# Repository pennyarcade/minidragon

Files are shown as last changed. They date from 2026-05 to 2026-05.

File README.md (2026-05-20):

# MiniDragon

Schematics, hardware simulator and software files for the MiniDragon CPU. This is a from-scratch CPU that I designed and am implementing using transistors, capacitors, resistors and diodes. The goal is to make an 8-bit CPU that could be used for general-purpose computing. There are a lot of toy instruction sets floating around on the web. I chose instead to design my own, loosely based off of the PDP and 6502. It is a single accumulator design with a pair of 16-bit stack pointers and a pair of temporary 8-bit registers. Instructions are 8 bits, operands are 8 bits from memory, temporary registers or immediate, and running software can access all 16 bits of memory available to the CPU. Eventually, I want the assembled CPU along with some external RAM, ROM and a serial interface chip to be self-hosting. So, I hope to eventually have a built-in assembler or BASIC interpreter in the ROM.

## Layout

The layout is separated into logical components:

 * Microcode counter. This keeps track of what microcode in the current instruction we are operating on.
 * Instruction decoder logic. This consists of an instruction register and a series of ROM boards made out of jumpers. This uses the microcode counter as well as its own internal combinatorial logic to select one instruction and output control signals to the rest of the CPU.
 * Registers. These exist on various busses, and their input/output is controlled by the instruction decoder logic's control signals.
 * Constant circuits. These can output either a zero or an immediate value sign extended from the current instruction register. Their operation is controlled by the instruction decoder's control signals.
 * ALU. This is built out of a series of smaller components on its own internal bus. Selection of which operation as well as which input is controlled via the instruction decoder logic's control signals.
 * Flags handling. This consists of a few registers to hold flags generated by the ALU and put them on the data bus when appropriate. This is controlled via the control signal lines much like the rest of the non-instruction decoder components.
 * Memory interface. This provides the glue so that the CPU can be seen as having a set of address and data lines as well as an output enable and write enable line, much like a traditional non-SOC CPU.

### Internal Busses

 * 16-bit data bus. Most registers can only read from or write to the lower 8 bits of this bus, but some can also output their value to the upper 8 bits. Various 16-bit registers are able to read the entire 16-bit bus, and this is how the upper bits of the instruction pointer and stack pointers can be read. The lower 8 bits of this will feed the external data IO lines.
 * 16-bit address bus. This feeds the external address requests by the CPU and is driven by both the instruction pointer and stack pointers.
 * 16-bit ALU source bus. This allows the ALU A source to be controlled, so that various 16-bit registers we want to add/subtract from don't need to be placed in a temporary location.

### Registers

 * 16-bit instruction pointer register (IP), holding the address of the current instruction in memory. Its value can be placed on the address bus or ALU input bus and it can read from the data bus. Software can jump relative to the current instruction, as well as pushing the current IP to the stack (controlled by the PC combined register), pop the IP from the stack or jump to an immediate 16 bit address.
 * 8-bit instruction register (IR), holding the current instruction that was fetched from memory. It is write-only and feeds microcode decoding logic, but can read from the data bus. Software cannot directly set this, but memory is modifiable so self-modifying code is possible.
 * 8-bit accumulator register (A), holding the current accumulated result. It can read from and write to the data bus, and it can output to the ALU input bus. Many instructions available to software can directly manipulate this register. Its value can be moved to and from the P and C registers as well as added to the combined PC register, allowing it to be used for indirect memory address modes as well.
 * 8-bit ALU temporary register (B), holding a temporary value from the bus. It can read from and write to the data bus. Its output is also hardcoded to the second input of the ALU. Software has no capability to modify this register and it is used by various microcodes to accomplish virtually all CPU operations. When the ALU is operating on a 16-bit number, the B register will be sign-extended to 16 bits.
 * 8-bit memory page register (P) and 8-bit memory cell register (C), together holding a 16-bit address. The P and C registers can individually read from the data bus, and the combined PC value can be output to the address bus or the ALU input bus. Software can write to the P and C registers from the A register and can use the combined PC register contents to load from and store to memory. Some ALU operations allow the memory address pointed at by the PC register to be used as an operand for ALU operations against the accumulator (A). The current value of the instruction pointer (IP) can be pushed to or popped from memory referred to by this register. The current value of the shadow PC combined register can also be pushed to or popped from memory referred to by this register.
 * 8-bit shadow page register (SP) and 8-bit shadow cell register (SC), together holding a 16-bit address referred to as SPC. This is not directly addressable, but its current value can be pushed to or popped from the location pointed at by the PC register, and a SWAP instruction allows software to swap the PC and SPC registers.
 * 8-bit CPU data register (D), holding temporary values when the CPU is pushing or popping a 16-bit value off of the stack (PC). We could use the A register for this, but I wanted to make sure that the accumulator was not clobbered when performing stack operations. This is not user readable or writeable.
 * 8-bit temporary registers (U and V), available to the programmer for various operations. These can be moved to from A, swapped to from A or each other, loaded from and stored to memory, and can be used as operands for ALU operations against the accumulator (A).
 * 3-bit flags register, containing a carry flag (CF), a zero flag (ZF) and a shadow PC flag (PC). Software cannot directly set or clear the carry or zero flags, but both carry and zero flags are set appropriately when carrying out any ALU-based operation which sources from and stores to the A register. It is not directly readable by software but there exist skip instructions that allow software to conditionally execute a particular instruction if either CF or ZF is set or cleared. Additionally, several ALU operations allow using the carry flag as an input to chain operations together for 16 and 32 bit arithmetic. The PC flag is toggleable using a special SWAP instruction.

### Instructions

 * JRI - Jump relative to immediate sign-extended + 1. Assembler also supports labels. Can jump 32 forward or backward relative to next instruction. Specifically designed such that "JRI 0" jumps to the next instruction and is encoded as all zeros.
 * LOADI - Load immediate stored in next memory cell to A. Can load any 8-bit value. Skips over that value after executing since it is not a valid instruction.
 * ADDI - Add immediate sign-extended to A, no carry. Can add values between -32 and 31. Affects ZF and CF.
 * INV - Bitwise invert A. Affects ZF and CF.
 * SHL - Shift A left by 1, setting the bottom bit to 0, set carry to top bit shifted out. Affects ZF and CF.
 * SHR - Shift A right by 1, setting the top bit to 0, set carry to bottom bit shifted out. Affects ZF and CF.
 * RCL - Shift A left by 1, setting bottom bit to the carry flag, set carry to top bit shifted out. Affects ZF and CF.
 * RCR - Shift A right by 1, setting top bit to the carry flag, set carry to bottom bit shifted out. Affects ZF and CF.
 * ROL - Shift A left by 1, setting the bottom bit to the shifted out top bit, set carry to top bit shifted out. Affects ZF and CF.
 * ROR - Shift A right by 1, setting the top bit to the shifted our bottom bit, set carry to bottom bit shifted out. Affects ZF and CF.
 * ADD - Add contents of memory location PC to A register. Affects ZF and CF.
 * ADC - Add contents of memory location PC to A register, with carry in from flags. Affects ZF and CF.
 * AND - And contents of memory location PC against A register. Affects ZF and CF.
 * OR - Or contents of memory location PC against A register. Affects ZF and CF.
 * XOR - XOR contents of memory location PC against A register. Affects ZF and CF.
 * ADDU - Add contents of U to A register. Affects ZF and CF.
 * ADCU - Add contents of U to A register, with carry in from flags. Affects ZF and CF.
 * ANDU - And contents of U against A register. Affects ZF and CF.
 * ORU - Or contents of U against A register. Affects ZF and CF.
 * XORU - XOR contents of U against A register. Affects ZF and CF.
 * ADDV - Add contents of V to A register. Affects ZF and CF.
 * ADCV - Add contents of V to A register, with carry in from flags. Affects ZF and CF.
 * ANDV - And contents of V against A register. Affects ZF and CF.
 * ORV - Or contents of V against A register. Affects ZF and CF.
 * XORV - XOR contents of V against A register. Affects ZF and CF.
 * ADDPCI - Add immediate to PC. Can add any value between 1 and 32 inclusive. Since we only have the capability of sign-extending the bottom 4 or 6 bits of an instruction to use as an immediate, this intentionally chooses an instruction prefix which sets the 6th bit to 0, in order to simplify decoding logic as well as keep the immediate register simple. This is why there is a separate ADDPCI and SUBPCI instruction.
 * SUBPCI - Subtract immediate from PC. Can subtract any value between 1 and 32 inclusive. Much like ADDPCI, this uses a clever trick where the 6th bit in the instruction prefix is set to 1, in order to correctly sign-extend the immediate.
 * ADDPC - Add A register sign-extended from 8 to 16 bits to the PC register.
 * ATOP - Load contents of A register to P.
 * ATOC - Load contents of A register to C.
 * PTOA - Load contents of P register to A.
 * CTOA - Load contents of C register to A.
 * ATOU - Load contents of A register to U.
 * ATOV - Load contents of A register to V.
 * UTOA - Load contents of U register to A.
 * VTOA - Load contents of V register to A.
 * LOADA - Load contents of memory location pointed at by PC to A register.
 * STOREA - Store contents of A register to memory location pointed at by PC.
 * LOADU - Load contents of memory location pointed at by PC to U register.
 * STOREU - Store contents of U register to memory location pointed at by PC.
 * LOADV - Load contents of memory location pointed at by PC to V register.
 * STOREV - Store contents of V register to memory location pointed at by PC.
 * SKIPIF - Skip next instruction if carry/zero flag set/cleared. To save on decoding logic, the lower 3 bits of the SKIPIF instruction feed combinatorial logic in the flags register. This leaves us with four undefined instructions which would, if executed, choose to operate on either both or neither of the carry and zero flag simultaneously.
 * LNGJUMP - Jumps to address stored in memory location IP + 1 and IP + 2, stored in big-endian.  Skips over the two values after executing since they are not valid instructions.
 * SWAPAU - Swap contents of A and U registers.
 * SWAPAV - Swap contents of A and V registers.
 * SWAPUV - Swap contents of U and V registers.
 * SWAPPC - Swap PC and SPC registers, making the current PC into the shadow PC and vice versa.
 * PUSHIP - Subtracts two from PC, stores IP + immediate into location PC and PC + 1 big endian. Immediate can be a positive integer between 0 and 7 inclusive and is often non-zero in order to store the correct return address of a subroutine call.
 * POPIP - Jumps to data stored in memory location PC and PC + 1 big endian, adds 2 to PC.
 * PUSHSPC - Subtracts two from PC, stores SPC into location PC and PC + 1 big endian.
 * POPSPC - Loads SPC with value stored in memory location PC and PC + 1 big endian, adds 2 to PC.

### Assembler-Provided Macros

For convenience of programming without too much hassle, several assembler macros which are encoded to a series of the above instructions are available:

 * NOP - Perform no operation. Implemented as "JRI 0", which as noted above is encoded as a null byte.
 * HALT - Jump to self, loop forever. Implemented as "JRI -1".
 * ZERO - Zero the contents of A. Implemented as "LOADI 0".
 * SETPC - Set immediate value to PC register, clobbering A register. Sets PC to full 16-bit value. Implemented as a pair of "LOADI" instructions followed by the appropriate "ATOP" and "ATOC". Takes an optional second parameter which is applied as an integer offset to the 16-bit value.
 * INCPC - Add 1 to PC. Implemented as "ADDPCI 1".
 * DECPC - Subtract 1 from PC. Implemented as "SUBPCI 1".
 * STOREI - Stores immediate value to memory pointed at by PC register, clobbering A register. Stores full 8-bit value to memory. Implemented as a "LOADI" followed by a "STOREA".
 * NEG - Twos compliment negate A register. Implemented as an "INV" followed by an "ADDI 1".
 * INC - Increment A register. Implemented as an "ADDI 1".
 * DEC - Decrement A register. Implemented as an "ADDI -1".
 * RET - Return from subroutine (identical to POPIP).
 * JRIZ - Jump relative if zero flag set. Implemented using "SKIPIF" and "JRI".
 * JRINZ - Jump relative if zero flag not set. Implemented using "SKIPIF" and "JRI".
 * JRIC - Jump relative if carry flag set. Implemented using "SKIPIF" and "JRI".
 * JRINC - Jump relative if carry flag not set. Implemented using "SKIPIF" and "JRI".
 * LNGJUMPZ - Jump to address if zero flag set. Implemented using "SKIPIF", "JRI" and "LNGJUMP".
 * LNGJUMPNZ - Jump to address if zero flag not set. Implemented using "SKIPIF", "JRI" and "LNGJUMP".
 * LNGJUMPC - Jump to address if carry flag set. Implemented using "SKIPIF", "JRI" and "LNGJUMP".
 * LNGJUMPNC - Jump to address if carry flag not set. Implemented using "SKIPIF", "JRI" and "LNGJUMP".
 * CALL - Subtracts two from PC, stores the next instruction after this instruction to PC, then jumps to the immediate address. Return from this using “RET”. Implemented using a "PUSHIP" and a "LNGJUMP".
 * CALLRI - Subtracts two from PC, stores the next instruction after this instruction to PC, then jumps to the relative offset from the next instruction. Return from this using “RET”. Implemented using a "PUSHIP" and a "JRI" instruction, meaning it is only useful for subroutines located close in memory. However, it can save several bytes.
 * PUSH x - Subtracts operand size from PC, stores the value of A/U/V/IP/SPC into the memory location PC. This is simply a virtual instruction that maps to "STOREA", "STOREU", "STOREV", "PUSHIP" or "PUSHSPC", so that the correct instruction doesn't have to be remembered.
 * PUSHI - Subtracts 1 from PC, stores immediate to memory location PC, clobbering A register. Implmented as a "DECPC" followed by a "STOREI" macro.
 * PUSHADDR - Subtracts 1 from PC, stores low byte of 16-bit immediate value to memory location PC, clobbering A register. Then subtracts 1 again from the PC, stores the high byte of 16-bit immediate value to memory location PC, clobbering the A register again. Implemented as a pair of "DECPC" and "STOREI" macros. Takes an optional second parameter which is applied as an integer offset to the 16-bit value.
 * POP x - Loads the value of memory location PC into A/U/V/IP/SPC, adds operand size to PC. Works identically to "PUSH x" as a virtual instruction alias to several concrete instructions.
 * LOAD x - Loads the value pointed at in memory by PC to A/U/V. Alias for the various concrete load instructions, similar to "PUSH x" and "POP x".
 * STORE x - Stores the value in A/U/V into the memory location pointed at by PC. Alias for the various concrete store instructions, similar to "PUSH x" and "POP x".
 * SWAP x, y - Swaps the contents of a pair of registers. Valid pairs are either from A/U/V or PC/SPC. Alias for the various concrete swap instructions, similar to "PUSH x", "POP x", "LOAD x" and "STORE x".
 * MOV x, y - Moves the contents of the x register into the y register. Any register A/U/V/P/C can be moved to or from as long as one of the operands is the A register. Alias for the various concrete load instructions, similar to "SWAP x, y".

### Opcode Layout

The 8-bit space for a single opcode is split up in order to make it possible to decode instructions using the least amount of logic. There are some holes where future instructions might be added. For now, undefined instructions will produce undefined behavior in the CPU. As currently implemented, the control logic will output all 1's for all control signals of undefined or un-mapped instructions. For this layout, the following conventions are used:

 * Register name - Register names listed directly refer to the value of that register. So, `A + 1` would refer to an operation that takes the value of A and adds 1.
 * `>` - Right carat, implies that the result of the operation on the left is stored to register/location on the right.
 * `[` and `]` - Dereference. This implies that the value of what is inside the `[]` is an address where we will store. So `1 > [PC]` implies that the value of "1" would be stored to the 8-bit memory location referenced by the PC combined register.
 * `{` and `}` - Register operand from the opcode itself. Currently, register operands are defined as follows:
   * `00` - Undefined, no register mapping.
   * `01` - U register.
   * `10` - V register.
   * `11` - SRAM pointed at by PC register.

<pre>
opcpde            description                         implementation                 mnemonic        alias
----------------------------------------------------------------------------------------------------------

<b>y y y y y y y y   immediate op</b>
0 0 x x x x x x   jump to immediate offset            IP + imm + 1 > IP              JRI x
0 1 x x x x x x   add immediate to A                  A + imm -> A                   ADDI x

<b>1 0 0 y y y y y   stack immediate op</b> †1
1 0 0 0 0 x x x   push IP + immediate                 PC - 2 > PC, IP + imm > [PC]   PUSHIP x        PUSH IP + x

<b>1 0 0 s s y y y   arithmetic op with operand</b> †2
1 0 0 s s 0 0 0
1 0 0 s s 0 0 1   add from [PC]/U/V                   A + {ss} > A                   ADD/ADDU/ADDV
1 0 0 s s 0 1 0   add with carry from [PC]/U/V        A + {ss} + CF > A              ADC/ADCU/ADCV
1 0 0 s s 0 1 1   and from [PC]/U/V                   A & {ss} > A                   AND/ANDU/ANDV
1 0 0 s s 1 0 0   or from [PC]/U/V                    A | {ss} > A                   OR/ORU/ORV
1 0 0 s s 1 0 1   xor from [PC]/U/V                   A ^ {ss} > A                   XOR/XORU/XORV
1 0 0 s s 1 1 0   <i>see tables below</i>
1 0 0 s s 1 1 1   <i>see tables below</i>

<b>1 0 0 s s y y y   arithmetic op against U</b>
1 0 0 0 1 0 0 0
1 0 0 0 1 0 0 1   <i>add from U</i>
1 0 0 0 1 0 1 0   <i>add with carry from U</i>
1 0 0 0 1 0 1 1   <i>and from U</i>
1 0 0 0 1 1 0 0   <i>or from U</i>
1 0 0 0 1 1 0 1   <i>xor from U</i>
1 0 0 0 1 1 1 0   rotate left A                       A << 1 + ((A >> 7) & 0x01) > A ROL
1 0 0 0 1 1 1 1   rotate right A                      A >> 1 + ((A << 7) & 0x80) > A ROR

<b>1 0 0 s s y y y   arithmetic op against V</b>
1 0 0 1 0 0 0 0
1 0 0 1 0 0 0 1   <i>add from V</i>
1 0 0 1 0 0 1 0   <i>add with carry from V</i>
1 0 0 1 0 0 1 1   <i>and from V</i>
1 0 0 1 0 1 0 0   <i>or from V</i>
1 0 0 1 0 1 0 1   <i>xor from V</i>
1 0 0 1 0 1 1 0   rotate left with carry A            A << 1 + CF > A                RCL
1 0 0 1 0 1 1 1   rotate right with carry A           A >> 1 + (CF << 7) > A         RCR

<b>1 0 0 s s y y y   arithmetic op against [PC]</b>
1 0 0 1 1 0 0 0
1 0 0 1 1 0 0 1   <i>add from [PC]</i>
1 0 0 1 1 0 1 0   <i>add with carry from [PC]</i>
1 0 0 1 1 0 1 1   <i>and from [PC]</i>
1 0 0 1 1 1 0 0   <i>or from [PC]</i>
1 0 0 1 1 1 0 1   <i>xor from [PC]</i>
1 0 0 1 1 1 1 0   shift left A                        A << 1 > A                     SHL
1 0 0 1 1 1 1 1   shift right A                       A >> 1 > A                     SHR

<b>1 0 1 y y y y y   pc subtract op</b> †3
1 0 1 x x x x x   Subtract immediate from PC          PC - imm - 1 > PC              SUBPCI x

<b>1 1 0 y y y y y   pc add op</b> †4
1 1 0 x x x x x   Add immediate to PC                 PC + imm + 1 > PC              ADDPCI x

<b>1 1 1 0 0 y y y   register op</b>
1 1 1 0 0 0 0 0   load from address P + C to U        [P | C] > U                    LOADU           LOAD U
1 1 1 0 0 0 0 1   store to address P + C from U       U > [P | C]                    STOREU          STORE U
1 1 1 0 0 0 1 0   load from address P + C to V        [P | C] > V                    LOADV           LOAD V
1 1 1 0 0 0 1 1   store to address P + C from V       V > [P | C]                    STOREV          STORE V
1 1 1 0 0 1 0 0   swap A and U                        A > U, U > A                   SWAPAU          SWAP A, U/SWAP U, A
1 1 1 0 0 1 0 1   swap A and V                        A > V, V > A                   SWAPAV          SWAP A, V/SWAP V, A
1 1 1 0 0 1 1 0   swap U and V                        U > V, V > U                   SWAPUV          SWAP U, V/SWAP V, U
1 1 1 0 0 1 1 1   swap PC and SPC                     PC > SPC, SPC > PC             SWAPPC          SWAP PC, SPC/SWAP SPC, PC

<b>1 1 1 0 1 y y y   memory op</b>
1 1 1 0 1 0 0 0   load page register from A           A > P                          ATOP            MOV A, P
1 1 1 0 1 0 0 1   load cell register from A           A > C                          ATOC            MOV A, C
1 1 1 0 1 0 1 0   store page register to A            P > A                          PTOA            MOV P, A
1 1 1 0 1 0 1 1   store cell register to A            C > A                          CTOA            MOV C, A
1 1 1 0 1 1 0 0   load U register from A              A > U                          ATOU            MOV A, U
1 1 1 0 1 1 0 1   load V register from A              A > V                          ATOV            MOV A, V
1 1 1 0 1 1 1 0   store U register to A               U > A                          UTOA            MOV U, A
1 1 1 0 1 1 1 1   store V register to A               V > A                          VTOA            MOV V, A

<b>1 1 1 1 0 y y y   status op</b> †5
1 1 1 1 0 0 0 0   invert A                            ~A > A                         INV
1 1 1 1 0 0 0 1
1 1 1 1 0 0 1 0   skip next instruction if CF         IP + 1 + CF > IP               SKIPIF CF
1 1 1 1 0 0 1 1   skip next instruction if !CF        IP + 1 + !CF > IP              SKIPIF !CF
1 1 1 1 0 1 0 0   skip next instruction if ZF         IP + 1 + ZF > IP               SKIPIF ZF
1 1 1 1 0 1 0 1   skip next instruction if !ZF        IP + 1 + !ZF > IP              SKIPIF !ZF
1 1 1 1 0 1 1 0   invert A                            ~A > A                         INV
1 1 1 1 0 1 1 1

<b>1 1 1 1 1 y y y   stack op</b>
1 1 1 1 1 0 0 0   jump to immediate                   [IP + 1] > IP                  LNGJUMP x
1 1 1 1 1 0 0 1   load immediate                      [IP + 1] -> A                  LOADI x
1 1 1 1 1 0 1 0   add to PC                           PC + A > PC                    ADDPC
1 1 1 1 1 0 1 1   pop IP                              [PC] > IP, PC + 2 > PC         POPIP           POP IP
1 1 1 1 1 1 0 0   push SPC                            PC - 2 > PC, SPC > [PC]        PUSHSPC         PUSH SPC
1 1 1 1 1 1 0 1   pop SPC                             [PC] > SPC, PC + 2 > PC        POPSPC          POP SPC
1 1 1 1 1 1 1 0   load from address P + C             [P | C] > A                    LOADA           LOAD A
1 1 1 1 1 1 1 1   store to address P + C              A > [P | C]                    STOREA          STORE A
</pre>

 * †1 This instruction occupies the same space as the ALU operations. This is why register operand {00} is undefined. The instruction decoder will not select the ALU operation decoder board when "PUSHIP" is detected.
 * †2 This might be slightly misleading, given that the register operand {00} is not only undefined but also not mapped to ALU operations. See †1 for details.
 * †3 Due to only being able to sign-extend the lower 4 or 6 bits of an instruction, this cleverly puts itself into an instuction slot where the 6th bit is 1.
 * †4 Due to only being able to sign-extend the lower 4 or 6 bits of an instruction, this cleverly puts itself into an instuction slot where the 6th bit is 0.
 * †5 I've shoved some arithmetic instructions that do not use a "B" operand here. We decode them versus a SKIPIF by doing an XOR/EQUALITY on the 2nd and 3rd bit, making them map to two places in the ISA. When in SKIPIF mode, we use the lower 3 bits as selector signals for combinatorial logic. The lowest bit is used as an "invert selected flags signal" bit, and the next two bits are used as "CF select" and "ZF select". This is why we can map unrelated instructions to when the last two bits are 00 or 11, since those would map to "neither CF or ZF" and "both CF and ZF" respectively.

## Design Concessions

As was the case with many 8-bit CPUs in the last century, this CPU does not have included memory, either volatile or non-volatile. It instead will assume an external chip or set of chips present on its external address and data bus. These chips, in the interest of practicality, will be standard TTL DIP package chips providing 32KB of SRAM, 30KB of ROM and 2KB of IO address space in which I am currently planning to place an 8-bit serial chip to talk to a VT-100 terminal. Other plans include an RTCRAM chip for settings and clock support, a GPIO chip, and room for additional expansion chips.

Due to the sheer number of parts involved in making a register as well as the control logic needed in order to select registers for ALU operations, there are only two scratch registers. Most intermediate values must therefore be stored on the stack. Various core library operations were sped up significantly when adding the U and V registers as slower stack manipulation operations could be dropped. Additional speedups as well as easier implementation of core functionality could be realized by adding additional scratch registers. However, this would increase the complexity of the instruction decoding logic and require a necessary juggling of instructions in the above table.

Similarly, due to the complexity of such a circuit, no number comparison instructions are present. Instead, comparison functions are implemented in the stdlib by bitwise comparing two numbers from top to bottom bit. This makes a lot of functions such as integer conversion and division functions much slower than they need to be. Due to this, I'm considering possibly adding a compare function to the ALU and placing it in place of the INV instruction. INV would move to the unused opcode in the status op block, at which case I would have room to implement a hardware NEG. I've experimented with this on a separate branch and the gains are significant. Alternatively, its possible to design an external math coprocessor. This is similar to contemporary CPUs with a floating point or math coprocessor so would not be out of the question. If this happens, the standard library should be updated to call the coprocessor instead of perofrming comparisons, multiplication and division on-CPU.

Because of the complexity of designing such a system from scratch, there are a lot of inefficiencies in how the various circuits are assembled. In many cases, buffers are not actually necessary and add to propagation delay. In order to make the project manageable by a single creature, I've decided to sacrifice any sort of speed for modularity. This will result in a CPU that can theoretically only operate at a clock cycle of ~100KHz. If I was to be a lot more dilligent I could probably get this up into the several hundered or even megahertz level, but it isn't worth it. Perhaps in a second, miniaturized TTL-only iteration?

### Memory Layout

As alluded to above, the MiniDragon can access a full 64k of address space because all memory operations are based on either the IP or the SP registers. No banking is necessary so no special hardware is required in order for software to access the full range of memory. The MiniDragon provides no custom IO port instructions so all hardware access must be performed through memory-mapped IO. Because virtually all hardware chips designed in the era MiniDragon is targetting only used a few registers, that means the address space for hardware itself can be very small. MiniDragon takes advantage of this by minimizing the memory-mapped IO portion of its address space.

The boot ROM is mapped to the bottom 30KB of addressable memory. Because 30KB EEPROMs do not exist, a 32KB EEPROM will be used to provide this, with the top 2KB invisible to the CPU. The boot ROM is mapped to the beginning of the address space because MiniDragon's reset vector is 0x0000. The next 2KB of memory will be reserved for memory-mapped IO. 2KB was chosen specifically because the MiniDragon is slated to allow for 8 expansion cards for IO expansion circuits. 2KB divides by 8 cleanly, meaning that each expansion card will receive 256 bytes of memory to place any necessary registers. In practice this will be accomplished by a 3 to 8 address bus decoder chip providing a chip select signal to each card, along with 8 address lines, 8 bidirectional data lines and a few miscellaneous signals. The top 32KB of memory will be mapped to a 32KB SRAM chip. This makes setting the stack pointer relatively convenient since it can be placed at 0x0000 during boot and the first PUSH instruction will wrap it around to the top of memory where the SRAM chip sits.

## Build Progress

As I continue with both the physical and virtual implementations of MiniDragon its been useful to break down the work into more manageable tasks. A side benefit is that I get to see things moving closer to completion at a much smaller scale. As of last calculation, I am 86% finished with the whole project.

### Hardware

As a whole, the hardware side of MiniDragon is 82% complete.

 - instruction decoder: 48% complete
    - Design work and diagramming for the instruction decoder core, including microcode counting, distribution logic, demultiplexing logic and associated glue is finished. Diagramming for exact connections to various instruction ROM boards is not complete. Of the 56 instructions (55 real instructions and a microcode board for the shared load instruction step) 26 instructions are fully hooked in and the shared load step is wired up. The instruction decoder core is fully built and integrated into the physical build.
 - special registers: 100% complete
   - All design work and diagramming for necessry circuits is completed. Registers that can be read in order to perform conditional logic as well as source immediate values are completed and fully integrated onto the physical build.
 - general purpose registers: 100% complete
   - All design work and diagramming for the eight general purpose registers is completed. All registers (A, B, D, U, V, IP, PC and SPC) are built and fully integrated into the physical build.
 - ALU: 100% complete
   - The ALU core is completely designed, laid out and documented. Tested and fabricated designs for ADD, INV, OR, AND, XOR, SHL and SHR are integrated into the physical layout. The ALU is decomposed into seven core functions that each generate their own output and carry flag, along with a shared zero flag generator and a carry flag selector circuit.
 - memory interface: 100% complete
   - The MiniDragon CPU is designed to appear like a standard 80's TTL CPU from external components' perspective. This means 16 output "pins" for address lines, 8 bidirectional "pins" for data lines, and a few crucial control signals brought out. These signals include a negated write enable and read enable signal, a negated reset signal and a buffered clock signal. It should be noted that all of these signals (save for the clock) are asynchronous, but the write enable line does pulse low with the clock transition since various memory chips use the low to high transition as their write signal. All signals are TTL level and impedance compatible, and the bidirectional data bus uses TTL-compatible tri-state logic.
   - Additional circuitry that is not technically part of MiniDragon but will be necessary for its execution include a serial chip for IO, glue logic to support address decoding, a ROM chip and an SRAM chip to provide nonvolatile and volatile storage. These will be built using off-the-shelf TTL-compatible 7400 logic and ASICs since they aren't part of the CPU itself and their progress is detailed under the external boards bullet below.
 - power distribution: 100% complete
   - I went with an adjustable 5V switching mode power supply that can supply the necessary amperage (5+ amps estimated at this point) along with a few digital readouts sprinkled across the board for fine adjustments. The circuits are fairly sensitive to core voltage being at or slightly above 4.75V so the main power supply is turned up to about 5.60V to accomodate voltage sag in the power distribution circuits.
 - debugging boards: 100% complete
   - Various debugging boards, used mostly for setting hand-selected values on various busses are designed and fabricated. They are currently in use both as tools for helping test boards during bring-up and as a simulated memory interface for board integration and system testing.
 - external boards: 0% complete
   - The RAM/ROM board, peripheral interface board, cartridge control peripheral card and serial interface peripheral card have yet to be fully designed. I have partial designs for each board as well as a good idea of the memory map for the system. While these boards are not technically part of the MiniDragon CPU itself, they will be needed if I want to run software on the physical MiniDragon.

### Software

As a whole, the software side of MiniDragon is 85% complete.

 - assembler/disassembler: 100% completed.
 - compiler: 100% completed.
 - CPU simulator: 100% completed.
 - system emulator: 100% completed.
 - stdlib: 100% completed.
 - BIOS: ~10% completed.
   - I've decided on the R6551AP for serial support and have started work on the BIOS/boot ROM. This mostly consists of serial driver code and some VT-100 routines for basic string input and output, but also includes stdlib functions for string manipulation, fixed point conversion, integer conversion and math operations that aren't intrinsic to the CPU.

### Eratta

Various bugs have come up in board designs that weren't discovered until well after they were integrated. So, while I'm not going to fix those bugs, they're documented here including any workarounds.

 - 4-bit register boards have an enable input weight of 4 instead of 1. This means that anything driving a register enable signal will see a single register board as the equivalent of four logic boards. Thus, anything needing to interface with a register's enable input needs to support a fan-out of 4 instead of 1. In practice this means that a single control signal driving a pair of registers has a smaller threshold than normal where all of the bits properly respond to the enable signal. A simple workaround is to use a double-inverting logic buffer to isolate individual registers and amplify control signals. This is done on various boards in the MiniDragon physical layout and provides an added bonus of visibility on the board itself when a control signal is active.

 - 3-bit dynamic ROM enhancer boards do not stop asserting when their enable signal is low. These were designed to be run in parallel but unfortunately a design bug means that when they are disabled they overpower other boards connected to the same ROM bits, forcing the value to be 0 no matter what the other boards are asserting. This turns out to only be a problem in one instruction decoder board which needed 8 values instead of 4. For that, an enhanced dynamic ROM enhancer board which takes a 3 bit address instead of a 2 bit address was designed. In the rest of the spots where these boards exist this flaw does not impede their use.

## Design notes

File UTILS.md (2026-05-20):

# MiniDragon Assembler and Compiler Utils

A collection of utilities for working with MiniDragon assembly and MiniPy source files.

## Installation

To install these files, use the following one-liner:

```
pipx install git+https://github.com/DragonMinded/minidragon.git
```

To upgrade once you've installed, use the following one-liner:

```
pipx upgrade minidragon
```

To uninstall these files, use the following one-liner:

```
pipx uninstall minidragon
```

For help and instruction on setting up `pipx` on your computer, visit [pipx's installation page](https://pipx.pypa.io/stable/installation/).

## Utilities

The following utilities will be installed into your system path by `pipx`:

 - `minidragon-assembler` - Utility to take valid MiniDragon .S assembly files and output assembled binary suitable for burning to an EPROM or running in the emulator.
 - `minidragon-compiler` - Utility to take valid MiniPy .py source files and output assembly files suitable for linking into a ROM using the assembler.
 - `minidragon-emulator` - Utility to take an assembled .bin file and emulate the MiniDragon executing this ROM.
 - `minidragon-simulator` - Utility to take either a full .S listing or a .bin assembled ROM file and simulate the CPU on a line-by-line-basis.

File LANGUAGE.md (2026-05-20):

# MiniPy Language Specification

Included in the software tooling for the MiniDragon CPU is a compiler that takes a variant of Python informally referred to as MiniPy and emits assembly listings that can be assembled by the assembler to burn onto an EPROM, run through the included system emulator or run through the simulator/debugger. This document serves as the langauge specification for MiniPy.

## Lexical Analysis

MiniPy entirely reuses the Python grammar for source file parsing. For the full grammar specification you can see the [Full Grammar Specification](https://docs.python.org/3/reference/grammar.html) from the Python documentation. The lexer and parse tree uses [LibCST](https://github.com/Instagram/LibCST). What this means in practice is that any file which is valid syntax according to Python will also be valid syntax according to MiniPy.

## Type System

Unlike standard Python, MiniPy requires full type specification to compile. There are no objects so there is no duct typing. Instead, type inference in the compiler verifies the soundness of expressions and function calls based on the declared types. The standard data types include integers, strings, characters and booleans. Additionally, you have the option of declaring any variable constant, at which point the compiler will forbid any mutation of the variable such as assignment or string modification after the variable has been declared and assigned to.

Types are provided in the same manner as type hints in standard Python. This means that function parameters and returns are required to be typed. Additionally, all variable definitions are required to be typed. Note that MiniPy treats the first assignment of a local variable that hasn't been declared global as the definition of the variable. Unlike some old flavors of C and like Python, variable definitions are allowed anywhere. Unlike Python and like C langauges, however, variable scope is limited to the block of code in which the variable was defined. Like standard Python, it's possible to declare a variable with a type and not assign to it until later. Note that if you attempt to use a variable after declaring it but before initializing it, the compiler will flag an error on the line.

MiniPy will perform all expression evaluation at the width of the destination in an assignment, function call or return statement. Said in another way, if you assign the result of an expression to an 8 bit integer, the intermediate calculations will all be done with 8 bit data types as well. Integers that are larger than the data type will be truncated at the point of reference in the expression. Integers that are smaller than the data type will be zero-extended or sign-extended, depending on whether they are unsigned or signed integers, at the point of reference in the expression. This goes for expressions in a function call parameter as well as expressions in a return statement. In the former, the width of the parameter itself according to the function definition will be used. In the latter, the function return type width will be used.

The valid types available to MiniPy programs are as follows.

---

`uint8`

 > An 8 bit unsigned integer, capable of representing values from 0 through 255. Takes up one byte of memory on the stack.

---

`int8`

 > An 8 bit two's compliment signed integer, capable of representing values from -128 through 127. Takes up one byte of memory on the stack.

---

`uint16`

 > A 16 bit unsigned integer, capable of representing values from 0 through 65535. Takes up two bytes of memory on the stack, stored as big-endian.

---

`int16`

 > A 16 bit two's compliment signed integer, capable of representing values from -32768 through 32767. Takes up two bytes of memory on the stack, stored as big-endian.

---

`uint32`

 > A 32 bit unsigned integer, capable of representing values from 0 through 4294967295. Takes up four bytes of memory on the stack, stored as big-endian.

---

`int32`

 > A 32 bit two's compliment integer, capable of representing values from -2147483648 through 2147483647. Takes up four bytes of memory on the stack, stored as big-endian.

---

`char`

 > An 8 bit extended ASCII character, capable of holding any of the 8 bit extended ASCII values including the null byte. Takes up one byte of memory on the stack or one byte of memory in a string.

---

`str`

 > A null-terminated extended ASCII string, capable of holding up to `127` characters including the null terminator byte. Implemented as a 16 bit pointer to a memory address in RAM. Takes up two bytes of memory on the stack, stored as a big-endian pointer. Note that non-constant strings are required to specify the desired maximum storage length. This is done using bracket notation as demonstrated in examples below. The exception to this is in functions returning strings which explicitly return a variable or constant. In this case, you are free to declare that your function returns a `str` without using bracket notation to define a maximum storage length.

---

`bool`

 > A boolean, holding the value of `True` or `False`. Under the hood this is mapped to a single byte holding either the value `0x00` for `False` or `0xFF` for `True`.

---

`void`

 > The lack of a value. This is only ever used to specify functions that do not return a value and cannot be used for function parameters, local or global variables.

Additionally, any parameter, function return or local variable can be declared constant by using the `const[]` modifier. When a variable is made constant it cannot be assigned to or modified after its declaration. Attempting to do so will generate a compile error on the offending line. Declaring a global varible as `const` will cause the compiler to place it into the code section of the compiled output.

Examples of various types are as follows.

---

`a: int16`

 > Declare a local variable `a` as a signed 16 bit integer. The compiler will allocate space on the stack for this variable at time of allocation.

---

`a: const[uint32] = b + 37`

 > Declare a local variable `a` as a constant unsigned 32 bit integer and assign it the value of `b + 37`. Note that it is a compile error to declare a constant variable without assigning it a value since it would be impossible to mutate the value at a later time.

---

`a: str[32] = ""`

 > Declare a local variable `a` as a string with a maximum storage of 32 bytes including the null terminator and initialize it to the empty string.

---

`def func(param1: int8, param2: const[int8]) -> bool: ...`

 > Declare a function which takes two parameters and returns a boolean. `param1` is an 8 bit signed integer and `param2` is a constant 8 bit signed integer. This means that within the function code is free to assign to `param1` but attempting to modify `param2` will result in a compiler error. The compiler will use the types of the parameters and return to allocate space on the stack for the parameters and the return itself. Note that the example provides an ellipses (`...`) instead of a function body. This would normally result in a compiler error unless you were declaring an `extern` function but has been shown here to demonstrate how a function prototype might look without needing to specify a function body.

---

`def func(param: const[str]) -> void: ...`

 > Declare a function which takes a single string parameter and does not return a value. `param` is a constant string, meaning the function cannot modify or mutate the string in any way.

## Supported Python Features

MiniPy only supports a limited subset of Python's language features. Care has been taken to conform to Python behavior and expectations within that subset wherever possible. However, you are coding for an extremely limited and slow custom ISA so some deviations and compromises should be expected.

Please note that while standard Python is fully object-oriented, objects do not exist in MiniPy. There is no dotted notation support for accessing object attributes, no ability to define classes, and no support for built-in objects. There are no higher level data types such as tuples, dictionaries, sets, lists, or similar. Data types that are supported have concrete limits to their use.

### Integer Support

MiniPy supports integer arithmetic on 8 bit, 16 bit and 32 bit integers. It has support for both signed and unsigned arithmetic, although divide and modulo are only implemented for unsigned integers. Unlike standard Python, you must specify the width of your integer variables and there is no support for integers that do not fit within a 32 bit data type. The following operations are supported for unsigned integers: `+` (addition), `-` (subtraction), `*` (multiplication), `/` (division), `%` (modulo), `&` (bitwise and), `|` (bitwise or), `~` (bitwise not), `^` (bitwise xor), `<<` (logical shift left), `>>` (logical shift right). Additionally, all previously listed operations except for `/` and `%` are supported for signed integers. Additionally, Python's augmented assignment operators are fully supported for all operations that are supported normally.

Integer arithmetic that causes overflow does not automatically resize the integer to a larger version so care must be taken to choose the integer data type that will adequately fit the calculations you wish to perform. Do note that larger integers are slower to operate on due to the MiniDragon being an 8 bit CPU at its core. Therefore, there is a direct trade-off between range of integers available and the speed at which calculations against those integers can be done. For the best speed, stick with 8 bit integers for everything that does not need more as most basic operations are mapped directly to CPU instructions.

Examples of various operations are as follows.

---

`a: uint8 = b + c`

 > Adds the integers `b` and `c` together and places the result into a newly-defined variable `a`. The operation will be performed with 8 bits of precision due to the destination of the expression being an 8 bit integer. If `b` or `c` are larger integers they will be truncated to 8 bits before the addition is performed.

---

`a += 5`

 > Adds 5 to the already-defined integer `a`. Note that this requires `a` to already exist since it is adding 5 to it, so `a` will have been defined with a type on a previous line.

---

`a: int16 = b - c`

 > Subtracts the value in `c` from `b` and places the result into a newly-defined variable `a`. The operation will be performed with 16 bits of precision. If `b` or `c` are larger than 16 bits, they will be truncated to 16 bits before the operation is performed. If `b` or `c` are smaller than 16 bits, they will be sign-extended to 16 bits before the operation is performed due to the fact that the result of the operation is a signed integer. If `a` was instead defined as a `uint16` then smaller integers would be zero-extended instead.

---

`a = (a + 1) & 0x3F`

 > Caculates the value of `a + 1` and then boolean ands the result against `0x3F` before assigning the result back to `a`. This effectively creates a counter that will increment `a` by `1` whenever it is called until it hits `63` where it will wrap back around to `0` on the next execution.

### String Support

MiniPy supports a string data type and basic operations on strings. Strings work similarly to their counterpart in Python and unlike `char *` style arrays in C-like languages. That is, strings are passed by value, not by reference. Assigning a string to a variable makes a copy of that string such that modifying the variable later will not affect what it was assigned from. Strings support indexing by both an integer to access the character at a specific index as well as indexing by slice in order to return a substring consisting of the characters at the beginning to the end index.

Unlike Python, MiniPy lets you assign a character to an index in a string. This is because strings are mutable in MiniPy. Note that MiniPy only supports strings up to 127 characters in length and has no support for multi-byte unicode values. There is no support for Python's `encode()` and `decode()` functions and there is no support for raw bytestrings because a MiniPy string is effectively a null-terminated bytestring. Unlike Python, each individual character in a string has the data type of `char`, not `str`. That means that performing an operation such as `string[5]` will return a `char` data type, whereas performing an operation such as `string[5:6]` will return a `str` data type.

Note that, for speed reasons, when the compiler can prove that there is no way to accidentally cause aliasing issues, strings will be represented under the hood as a reference to another string instead of a full copy. This only happens with constant strings that are assigned to from a string literal, a global constant string, a function marked as returning a constant string, or another local constant string that was assigned to from one of these categories. Functions are only allowed to be marked as returning a constant string if the value they are returning fits within one of these categories as well. This support for references under the hood extends to string function parameters that are marked as constant. In order for the compiler to guarantee correctness, functions declared as returning a constant string with `const[str]` are checked to ensure that all of their returns match the above rules. Functions which attempt to return non-constant expressions or even local constants that were derived from non-constant expressions will be flagged with a compiler error.

Examples of various operations are as follows.

---

`a: str[16] = ""`

 > Declares a string that can hold at most 16 bytes including the null terminator and initializes it to an empty string.

---

`a += b`

 > Concatenates the value of `b` to the end of an existing string `a`. If `b` is a string as well, this is equivalent to the C function `strcat(a, b)`. If `b` is a character, this appends the character to the end of the string, updating the null terminator as appropriate.

---

`ch: char = a[5]`

 > Grabs the sixth character out of the string `a` (string indexes are zero-based in MiniPy just as they are in standard Python) and assigns it to the newly declared character `ch`. Note that unlike standard Python, MiniPy character indexes are not memory safe. That means that if your string is only 3 characters long and you ask for a character at index 5 you will get a garbage result.

---

`b: str[8] = a[3:7]`

 > Declares a new string `b` and then assigns it the slice of `a` starting at index 3 and ending at index 7. Supposing `a` were to hold the value "Hello, world" then after this operation `b` will now hold "lo, ". Note that string slices are memory safe just as they are in standard Python. That means that if a string is not long enough for the slice index you should expect the result of the slice to be shorter than specified. For instance, if `a` were to hold just the string "Hello" and you were to ask for the above slice, `b` would end up containing "lo. Note that slices with no beginning and slices with no end are both supported.

---

`a = a[:5]`

 > Truncates an already-defined string `a` to just the first 5 characters. If `a` does not contain 5 characters then this has no apparent effect.

---

`l: uint8 = len(a)`

 > Calculates the length of string `a` and places the result in a newly-declared integer `l`. This is equivalent to the C function `strlen(a)`.

---

`val: str[32] = "Value: " + str(v)`

 > Converts the already-defined variable `v` to a string and concatenates it with a string constant and then assigns the result to a newly-declared string `val`. Supposing `v` was an integer holding the value `123`, you should expect that after executing this statement that `val` would contain "Value: 123". Similarly, if `v` was a boolean holding the value `True`, you should expect that after running this statement `val` would contain "Value: True".

---

`result: str[64] = f"The result of {a} added to {b} is {a + b}."`

 > Evaluates an f-string expression which references two previously-defined integer variables `a` and `b`, assigning the result to the newly-defined string `result`. Supposing `a` held the integer value `5` and `b` held the integer value of `7`, then you should expect `result` to contain "The result of 5 added to 7 is 12.". F-string expressions support all embedded expressions that MiniPy would otherwise support on a standalone line. Note that MiniPy has no support for format specifications such as `!r`.

### Boolean Support

MiniPy supports a boolean data type to represent comparison expressions. It has limited support for automatic conversion from truthy values to boolean values, specifically when non-booleans are used in `if` statements, `while` loops and conditional expressions. In the case of explicit or implicit conversion to boolean, Python's truthy rules apply to MiniPy. Integers are seen as truthy if they are non-zero, and falsey when they are zero. Strings are considered truthy if they contain one or more characters, and falsey if they are empty or zero-length. Characters are considered truthy when they represent anything other than the null byte, and falsey when they represent the null byte. Internally, `False` is represented as a byte with all bits cleared (`0`) and `True` is represented by a byte with all bits set (`255`). This only matters in the case of `peek()` and `poke()` which are documented below.

Boolean expressions are short-circuiting and evaluated from left to right. MiniPy does not support comparing different data types, such as strings against characters, or integers against booleans. Attempting to do so will result in a compile-time error on the offending line. The only exception to this is in if statement tests, while loop tests and if expression tests where a non-boolean expression is supplied but not compared against anything. In this case, MiniPy will behave the same as standard Python and evaluate the expression for "truthy" or "falsey" behavior. For integers and characters, a value is considered "truthy" if the value is non-zero, and "falsey" if the value is zero. For strings, a value is considered "truthy" if the string is non-empty (contains one or more characters that are not the null terminator) and "falsey" if the string is empty (the first character is the null terminator).

Examples of various operations are as follows.

---

`a: bool = param1 == param2`

 > Evaluates the equality check `param1 == param2` and assigns the result to the newly-created boolean variable `a`. Note that equality checks are valid only against variables and constants of the same data type. Attempting to, for instance, compare an integer against a string will result in a compile-time error. Note also that there is support for checking equality for all supported data types.

---

`a: int8 = -5 if x > 3 else 5`

 > Evaluates an if expression with the test `x > 3` and assigning the result to a newly-defined variable `a`. If `x` is indeed greater than 3, you should expect that `a` will end up with the value `-5`. If not, you should expect at `a` will contain the value `5`.

---

`a: bool = bool(someStr)`

 > Looks at an existing variable `someStr`, assumed to be a string in this case, and evaluates it for "truthy" or "falsey" contents, assigning that to the newly-created variable `a`. If the string in question is empty, then you should expect `a` to be set to `False`. Otherwise, you should expect `a` to be set to `True`.

## Control Flow Support

MiniPy supports standard `if`/`elif`/`else` statements for directing control flow with identical semantics to Python. It is perfectly valid to use a `return` statement within an if body similar to standard Python. It supports `while` statements as well, with support for the optional `else` case which is only executed if the while loop is not terminated early with a `break` statement. While loops fully support both `break` and `continue` as well as returning early from a function using the `return` statement. For statements are supported in limited context. MiniPy does not support iterators generally but provides two iteration styles for Python-style for loops. The first is the `range()` intrinsic which behaves identically to the [Python range](https://docs.python.org/3/library/functions.html#func-range) function in standard Python. The second is iterating over characters in a string. Note that much like `while` statements, `for` statements support the optional `else` clause as well as `break`, `continue` and `return` to early exit or change loop flow.

Both `if` and `while` statement expression evaluation is short-circuiting. Both `if` and `while` also support automatic coersion of truthy values. That means that instead of writing something like `if len(str) > 0:` you can instead write the more pythonic `if str:`. Note that the latter form is also faster as it does not need to evaluate the string's length and then compare it against an integer. Under the hood the compiler can optimize the second form to just check the first character of the string against the null terminator byte. Control flow statements can be nested arbitrarily and with no restrictions to depth.

Examples of various control flow statements are as follows.

---

```
var: int8 = 5
if someVal > 10:
   var += 2
```

 > This chunk of code will define a new local variable `var` which is a signed 8 bit integer. Then, given an existing variable `someVal`, if `someVal` is greater than `10` adds two to `var`. Note that `if` statements do not necessarily need an `else` statement. If omitted, the compiler will simply generate code that skips over the body of the `if` statement if the conditional is false.

---

```
if someVal and someFun(someVal):
   someVal = otherVal
```

 > This chunk of code will conditionally set the existing and previously defined `someVal` to the same value as `otherVal` as long as the `if` statement conditional is true. In this case, `someVal` can be any data type since the compiler will evaluate both parts of the `and` expression for truthiness. It can be a string, in which case the left hand side will evaluate to `True` if the string is non-empty. It can be an integer, in which case the left hand side will evaluate to `True` if the integer is non-zero. It can be a boolean which will be evaluated directly. It can be a character, in which the left hand side will evaluate to `True` if the character is not the null character. Note that the function `someFun` is only called with the value `someVal` if the left hand side evaluates to `True`. If not, the right hand side is skipped entirely since the compiler performs short circuiting on conditional expression evaluation.

---

```
local: str[8] = "hello"
count: int8 = 0
while count < 5:
    if local[count] == '!':
        break
    if local[count] == '@':
        count += 2
        continue
    count += 1
else:
    count -= 5
```

 > This chunk of code demonstrates a couple of concepts. First, it shows how to create a `while` loop with a conditional. Second, it shows that while loops can use `break` or `continue` to early exit from the loop or skip over the rest of the body of the loop and resume from the top. Third, it shows off both standard Python and MiniPy's support for the `else` case in loops. This is a lesser-known feature of Python that allows you to conditionally run code only if the loop was not exited from early. That means if a `break` statement is ever executed, then the code will jump directly past the `else` clause. If the loop exited due to the loop conditional `count < 5` becoming false, then the code will jump to the `else` body and execute the code therein. Note that just like with `if` statements, you do not need to provide an `else` statement for `while` loops. Omitting this statement is perfectly allowed.

---

```
i: uint8
j: uint8 = 0
for i in range(5):
    j += 1
```

 > This chunk of code demonstrates the standard way of creating a `for` statement in both Python and MiniPy. The `range()` intrinsic, when given a single parameter, will generate an iterator that loops through the values `0`, `1`, `2`, `3` and finally `4`. You can think of `for` statements in this format as having an equivalent C representation of `for(int i = 0; i < 5; i++)`. Note that this particular example does not show any use of a `break`, `continue`, or an `else` clause on the `for` statement itself. If the example code were to use a `continue` statement, the code would begin execution again at the top of the body of the `for` statement after incrementing the loop counter `i` and checking it against the terminating condition. These are all supported in an identical fashion to `while` statements. Note that there is one key difference between this code and standard Python code. In standard Python, the value of `i` after the loop exits will be `4` because Python is generating an actual iterator under the hood and the last value in that iterator is `4`. In MiniPy, the value of `i` after the loop exits will be `5` because MiniPy evaluates the loop iterator (which is implicitly `1` in this case) before checking the termination condition.

---

```
i: uint8
j: uint8 = 0
for i in range(1, 9, 2):
    j += 1
```

 > This chunk of code demonstrates that the `range()` intrinsic can also be used to specify a beginning value, an end value and an increment value. The `for` statement here would have the equivalent C representation of `for(int i = 1; i < 9; i += 2)`. Both standard Python and MiniPy allow you to specify a `range()` intrinsic with a single, two, or three values. In the first case, the value specified is the end value, and the compiler will create a loop for you starting at `0`, incrementing by `1` each loop, and terminating when the loop variable hits the end value. In the second case with two parameters, the compiler will generate a loop for you starting at the first value provided, incrementing by `1` each loop, and terminating when the loop variable hits the second value provided. In the third case with three parameters, the compiler will generate a loop for you starting at the first value provided, incrementing by the third value each loop, and terminating when the loop variable hits the second value provided. Variables and expressions can be used for any of the parameters to the `range()` intrinsic, but do note that both the end and increment expression will be evaluated on every iteration. Note also that `break`, `continue` and an `else` clause are all valid in any of these types of `for` loops.

---

```
someStr: str[8] = "hello":
ch: char
sum: uint8 = 0
for ch in someStr:
    sum += ord(ch)
```

 > This chunk of code demonstrates that you can use a string as an iterator for a `for` statement. The code here shows an incredibly simple checksum algorithm which simply computes the sum of all characters in the string `someStr`. The loop will iterate over each character in the string, in order, until the null terminator character is hit. Both `break` and `continue` work here as expected, as does the `else` clause. If all you need to do is access each character in a string in order without the index, this form is faster than a similar `for` statement iterating over every position and fetching the character out of the string using `someStr[index]`.

### Function Support

MiniPy supports defining functions as well as calling functions in a similar fashion to standard Python. Parameters, including strings, are passed to functions by value except in very specific cases regarding string constants. Full support for default arguments is included, so if you specify a default for a given argument you do not need to provide a value when calling the function. Similarly, support for calling functions with keyword arguments is also available. This can come in handy when you want to specifically override only some defaults for a particular function. Note that MiniPy does not support dictionaries or lists, so support for `*args` and `**kwargs` is not available.

Function calls are handled on the stack, meaning that functions are allowed to call themselves recursively. Due to the fact that strings are assigned by value, it is safe to use strings in recursive functions. All other supported data types are similarly supported for recursive functions. Due to the fact that there are no interrupts in the MiniDragon CPU, there is no support for threading or and multi-processing support. Therefore, functions do not need to worry about reentrancy.

Examples of various function definitions and their calls are as follows.

---

```
def foo(p1: int8, p2: int8) -> int8:
    return p1 * 2 + p2

def main() -> void:
    local: int8 = foo(5, 7)
```

 > Defines a function `foo` which takes two parameters, both specified as 8 bit signed integers. The function itself is simply, evaluating the expression `p1 * 2 + p2` and returning that to the caller. Defines a function `main` which calls function `foo` with two parameters as required, assigning the result of the function to a newly-defined variable `local`. After executing this, you should expect that the value of `local` is `17`. If you were to try to call `foo` with more than or less than two parameters you should expect a compile-time error on the offending line.

---

```
def foo(p1: int8, p2: int8) -> int8:
    return p1 * 2 + p2

def main() -> void:
    local: int8 = foo(p2=5, p1=7)
```

 > Defines an identical function to the previous example, but shows off the function being called using named parameters in `main`. Since parameter names were used, the compiler will assign the values according to name instead of position. You should expect that the value of `local` is `19` after execution. Note that it is a compile-time error to specify a parameter both positionally and in a named parameter, to specify the same named parameter multiple times, or to leave out a parameter that does not have a default. Note that you are allowed to mix and match positional and named parameters as you see fit, but named parameters must always come after all positional parameters.

---

```
def foo(p1: int8, p2: int8 = 9) -> int8:
    return p1 * 2 + p2

def main() -> void:
    local1: int8 = foo(3)
    local2: int8 = foo(4, 6)
    local3: int8 = foo(7, p2=8)
```

 > Defines a function `foo` that has an identical body to the previous two examples, but provides a default value for the parameter `p2`. Note the three calling styles that used when invoking `foo` inside `main`. The first invocation leaves out the second parameter entirely. The compiler will substitute the default which is `9` in this case, assigning the result of `15` to `local1`. The second invocation supplies a value for both `p1` and `p2` positionally so the compiler will override the default, assigning the result of `14` to the variable `local2`. In the third invocation the caller is mixing positional and named arguments. The result of `22` will be assigned to the variable `local3`.

---

```
def lut(key: uint8) -> const[str]:
    if key == 0:
        return "foo"
    elif key == 1:
        return "bar"
    else:
        return "baz"

def op(prefix: const[str], key: uint8) -> str[16]:
    return prefix + " " + lut(key)

def main() -> void:
    local: str[32] = op("val:", 1)
```

 > Defines a function `lut` which operates as a look-up for a particular key. Note that the function is typed as returning a `const[str]`. This is allowed because the compiler can see that all valid return paths return a constant string. If the function were to return a local variable or the result of an expression, the compiler would not allow the function to be typed as `const[str]`. Defines a second function `op` which takes a `prefix` string and a `key` integer and computes a string concatenation with said prefix and the result of the `lut` function call. Note that since the function is returning the result of an expression, the function return must have a size specifier for the string. This is similar to how non-constant string variables must have a maximum size specification. Finally, the code is executed in main, assigning the result of `op` to the `local` string. Upon executing this code, you should expect the value of `local` to be `"val: bar"`.

### Global Variable Support

MiniPy's support for non-function execution is extremely minimal. Essentially the only thing you're allowed to do at the top level is import identifiers from another module or define a function. Arbitrary top-level code is not supported and will generate a compiler error on the offending line. However, defining global constants and global variables is supported. These work similarly to standard Python in that you can always access the value of a global variable that is in your scope without defining it as long as the name isn't shadowed by a local variable. Writing to a global variable requires declaring that you are accessing a global variable with the `global` keyword. Aside from that, globals are accessed in an identical manner to local variables and behave identically.

Initializing global constants is required since MiniPy requires that to use the `const[]` modifier you do not attempt to modify the variable once it has been declared. Initializing global variables is not required, but it is recommended to do so. Unlike local variables where the compiler will generate an error on the offending line if you attempt to use a variable that has been declared but not initialized, global variables have no protection against their use before initialization. Both global constants and global variables can only be initialized with a constant expression. That is, if the value of the expression is known at compile-time, the initialization is valid. This can include other global constants that were defined previously but not global constants that were imported from other modules.

Examples of various global variable uses are as follows.

---

```
GLOBAL_CONST: const[str] = "Hello, world!"
global_var: int8 = -37
```

 > Defines two global variables. The first one, `GLOBAL_CONST`, is a constant, meaning it cannot be mutated or overwritten after defining it. the second one, `global_var`, is non-constant and initialized to the value `-37`. Both can be read freely from any function in the same module. Both can be imported as identifiers to other modules and then used freely inside functions fonud in those other modules.

---

```
_running: bool = False

def setRunning(newVal: bool) -> None:
    global _running
    _running = newVal

def getRunning() -> bool:
    return _running
```

 > Defines a global variable `_running` that uses Python's convention of prefixing variables and functions that should not be imported with an underscore. Note that the compiler will freely let you import a function or global variable starting with an underscore but it is considered bad form. Also defines a setter and a getter function that allows code to call a function to set the value or get the value of `_running`, presumably designed as the public interface to this global variable. Notice that the setter function `setRunning` requires you to declare that you intend to use the global variable `_running` using the `global` declaration. Failing to do so will cause the compiler to assume you meant to assign to a local variable which has not been defined yet. The getter function `getRunning` follows Python's convention where reading the value of a variable first looks in the local stack and then falls back to globally defined variables.

## Compiler Intrinsics

Standard Python has support for a plethora of built-in functions. MiniPy replicates support for only a limited subset of these functions. Additionally, it adds a few intrinsics of its own. All supported intrinsics are documented here. The standard Python built-ins which MiniPy supports are listed below. In general, these should behave the same as their standard Python counterparts unless documented otherwise. For standard Python documentation of these intrinsicts, please see the [Built-In Functions](https://docs.python.org/3/library/functions.html)
documentation.

---

`len(str)`

 > Given a string literal or variable as its only argument, returns the length of the string in characters (not including the null terminator) as a `uint8`. Note that this only works with strings up to 127 characters long as that is the supported length limit of strings in MiniPy

---

`str(obj)`

 > Given any supported data type, returns a string conversion of that data type. Supports integers, booleans, characters and other strings. For strings and characters, the literal value as a string will be returned. For integers, the conversion of that integer to a decmial number including a negative sign will be returned. For booleans, the string "True" or "False" will be returned depending on the value of the boolean.

---

`int(obj)`

 > Given a string, integer or boolean, returns an integer conversion of that data type. For Strings, the conversion to an integer including a potential negative sign will be returned. For integers, the number passed in will be returned. For booleans, the number 1 or 0 will be returned for `True` and `False` which is identical to standard Python.

---

`abs(int)`

 > Given a signed integer, returns the absolute value of that signed integer at the same integer width.

---

`bool(obj)`

 > Given any supported data type, returns a boolean representing the truthiness of the data type passed in. For strings, returns `True` for any string that is not zero-length, and `False` for empty or zero-length strings. For integers, returns `True` for all nonzero numbers and `False` for zero. For booleans, returns the value passed in. For characters, returns `True` for all characters that are not the null byte, and `False` for the null byte.

---

`chr(int)`

 > Given an integer, returns the character equivalent of that integer.

---

`ord(char)`

 > Given a character, returns the integer equivalent of that character.

---

`hex(int)`

 > Given an integer, returns a string representing the hexidecimal value of the integer, including the `0x` prefix, mirroring standard Python.

---

`min(int, int)`

 > Given two integers, returns whichever one is smallest in magnitude.

---

`max(int, int)`

 > Given two integers, returns whichever one is the largest in magnitude.

---

`range(int, int=None, int=None)`

 > Given one, two or three integers, returns an interator useful in `for` statements. Note that this is only supported in `for` statements since MiniPy has no support for iterables otherwise. For more details on the parameters, please see Python's [range](https://docs.python.org/3/library/functions.html#func-range) documentation.

Additionally, MiniPy specifies a few intrinsics of its own. The MiniPy specific intrinsics are documented below.

---

`peek(addr, length=None)`

 > Given a 16 bit integer interpreted as a raw memory address, peek at that memory address and return the value contained therein. The return type of peek is dependent on the variable being assigned to in the expression that it is used in. When assigning to an 8 bit integer, peek will read the byte at the memory location and return that as an 8 bit integer. When assigning to a 16 bit integer, peek will read the two bytes at the memory address and subsequent memory address and interpret and return the value as a big-endian 16 bit integer. When assigning to a 32 bit integer, peek will read the four bytes at the memory address and subsequent three memory addresses and interpret and return the value as a big-endian 32 bit integer. When assigning to a character, peek will read the byte at the memory address and return it as a character. When assigning to a boolean, peek will read the byte at the memory address and return `True` for a non-zero byte and `False` for a zero byte. When assigning to a string, peek will perform a string copy starting at the given memory address until it encounters a null terminator byte. Optionally, for strings, you can specify a second parameter as an integer which will be treated as the length to copy. Strings longer than that will be truncated when the length limit is hit, and strings equal to or less than that length will be copied in their entirity.

---

`poke(addr, obj)`

 > Given a 16 bit integer interpreted as a raw memory address and a value to store, stores that value at that address. For integers, stores the value starting at that address in big-endian. For 8 bit integers, this only modifies the byte at the specified address. For 16 bit integers, this modifies the specified and subsequent byte. For 32 bit integers, this modifies the specified and subsequent three bytes. For characters, stores the character as a byte at the address specified. For booleans, stores either 0 or 255 depending on whether the value is `False` or `True`. For strings, copies the specified string starting at the memory address until the end of the string is reached. Note that the null byte is copied in this instance.

---

`cast(type, obj)`

 > Given a valid MiniPy type and an object, cast that object to that type. Currently only supports casting `uint16` to `str` and `str` to `uint16`. When performing a cast from a string to an integer, the resulting value that is returned is the memory address that the string resides at. When performing a cast from an integer to a string, the resulting value is a string that points at the given memory address.

---

`fixed(value, fracbits=8)`

 > Given an integer or floating point value and an optional fractional bits, converts that value to a fixed point integer that represents the decimal approximation of the floating point value. Note that in MiniPy, fixed point integers are always 32 bits wide.

## Import System

MiniPy supports relative imports similar to standard Python. Note that since MiniPy has no objects, you must use the `from <module> import X` syntax for importing. You can perform a star import much like standard Python, or you can explicitly specify the functions, global variables and global constants that you wish to import from the other module. Note that much like standard Python, importing only makes the references to those symbols available locally. Functions and variables that are imported from another module will work identically to functions and variables defined in the current module. The import system works similarly to standard Python where a module saved as `foo.py` is referred to as `foo` within the import statement. Modules can exist in subdirectories relative to the module performing the import, in which case you would specify the module using Python's dotted notation.

The compiler supports providing one or more library directories where it will additionally look for modules to import from if the module is not found in the directory relative to the currently compiled code. This is done through the `-l` or `--lib` flag. The resolution order is to check for local modules matching the specification first, and then to check each library path in the order that the libraries were specified on the command line. For instance, take the following directory layout, compiling `foo.py` by invoking the compiler in the top level directory `/example/` with the command-line `python3 compiler.py --lib lib/ src/foo.py`. When compiling `foo.py` it attempts to import with the line `from bar.baz import bla`. The compiler will check for a `src/bar/baz.py` file first since this is the directory `foo.py` exists in, and failing to find that will look for a `lib/bar/baz.py` file in the library directory specified.

```
/example/
|-- lib/
|   +-- bar/
|       |-- baz.py
|       +-- qux.py
+-- src/
    +-- foo.py
```

To reference a constant, variable or function that is defined only in assembly, you can use the `extern[]` modifier in the type definition for the varible or function. This functions similarly to importing the function or variable from another module in that it makes the thing you're declaring extern available for use within that module. Note that it is perfectly valid to import variables or functions from another MiniPy module that are declared extern. Under the hood, the `extern[]` modifier simply adds the variable type or function prototype to the list of available functions and assumes that there is a global label with a matching name which will be found in the final assembly listing when linking a full ROM.

Examples of using the import system are as follows.

---

`from hardware.serial import serial_init, serial_clear, serial_send`

 > Looks for the identifiers `serial_init`, `serial_clear` and `serial_send` in the module which implements `hardware.serial` and makes them available in the current module. That module could be the relative file `hardware/serial.py` relative to the module performing the import, or it could be the relative file `hardware/serial.py` existing in a library directory specified to the compiler with `-l` or `--lib`.

---

`def func(param1: int16, param2: int32) -> extern[bool]: ...`

 > Defines a function prototype for `func` which takes two parameters and returns a boolean. Note the `extern[]` modifier as well as the ellipses (`...`). The compiler will emit code that refers to the global label `func` which should be implemented in an assembly file and linked into the final build. Note also that it is possible to declare functions as extern instead of importing them from other modules. It is heavily recommended to not do this because prototypes could get out of sync with the actual function implementation. If this happens, the compiler will generate incorrect code to call the function and you will most likely end up with a crash. So, it's best to leave `extern[]` functions and variables for when you need to implement something in pure assembly and reference it from within MiniPy code.

## Included Libraries

MiniPy ships with a stdlib that was implemented in assembly as well as several libraries of functions implemented in MiniPy itself. Note that under most circumstances you should not need to call the assembly stdlib directly as the functionality has been mapped onto standard Python operations. However, if you so desire, you can call the functions directly in your code. Those functions aren't documented here because they're meant to be internal to the compiler. Instead, libraries that are intended to be used are documented here.

### sys

MiniPy has extremely limited support for Python's `sys` module. Absolutely no functions are supported but if you `import sys` you will have access to a few constants provided by the compiler that you can use in your code. Note that there is currently no support for `from sys import X` style importing of the pieces of `sys` that are supported. The bits of `sys` that are supported are documented below.

---

`sys.byteorder`

 > A string constant that is always equal to `big`, representing that MiniPy byte order is big-endian.

---

`sys.hexversion`

 > A uint32 integer that is set to the current version of the compiler, in the form of `0xAABBCCCC` where `AA` is an 8 bit major version, `BB` is an 8 bit minor version, and `CCCC` is a 16 bit point version. This should not be used for displaying version information, but can be used in integer comparisons if you need to switch on compiler version.

---

`sys.maxsize`

 > An integer that is set to the maximum size of a signed integer in MiniPy. This is the constant `2^31 - 1`.

---

`sys.maxunicode`

 > An integer that is set to the maximum supported unicode codepoint. Since MiniPy only deals with extended ASCII characters in strings and has no unicode support, this is set to `0xFF` or `255`.

---

`sys.platform`

 > A string constant that is always equal to `minidragon`. This can be used in code you intend to be semi-portable to determine if you're running under MiniPy or on a standard Python distribution.

---

`sys.version`

 > A string constant that is set to the current version of the compiler, in the form of `A.B.C` where `A` is the major version, `B` is the minor version and `C` is the point version. This can be used to display the version of the toolchain a particular program was compiled with.

### hardware.serial

A library for interacting with a VT-100 terminal over a serial port attached to a R6551AP serial chip in peripheral slot 0. This is the intended serial chip and peripheral slot number for the serial port on the actual MiniDragon as built. It is where keyboard input as well as text output is handled for interactive programs. To use any of the following functions, import them using a statement in the form of `from hardware.serial import bla` where `bla` is the function that you wish to support. Note that in order to successfully compile, the compiler will need to know where to find this library. So, you should use the compiler option `-lib /path/to/lib/` to point the compiler at the `lib/` directory included at the root of this repo.

---

`serial_init() -> void`

 > Initializes the serial chip so that it is ready to communicate with a VT-100 at 9600 baud, 8 bits, no parity bit, a single stop bit, and with XON/XOFF software control flow enabled. If you wish to use any serial features you must call this early in your program init, preferrably near the top of your `main()` function.

---

`serial_send_byte(byte: const[uint8]) -> void`

 > Send a single byte over the wire to the remote VT-100. Note that this takes a byte, not a character. To cast a character to a byte you can use the built-in `ord()` which works identically to its counterpart in standard Python. Note that while this function will wait until the transmit buffer is empty before sending the byte, it does not handle any XON/XOFF control flow from the remote side. So, this should be seen as an incredibly low level direct-access function to send a byte as soon as it is possible to do so.

---

`serial_has_byte() -> bool`

 > Returns a boolean `True` if there is a byte waiting in the receive buffer of the serial chip, or `False` if there is not. To receive that byte, call `serial_recv_byte()`.

---

`serial_recv_byte() -> uint8`

 > Receives a single byte from the serial buffer. If a byte is ready to be received, returns that byte. If not, then the behavior of this function is undefined and you will get whatever the R6551AP wants to return when reading a buffer that has no byte in it. This is likely to be a null byte, but the datasheet does not specify. Note that this does not handle any XON/OFF control flow so if the VT-100 has requested to turn off transmit you may read an `0x11` or `0x13` from this. So, this should be seen as an incredibly low level direct-access function to receive a byte should there be one to receive. To cast a byte to a character you can use the built-in `chr()` which works identically to its counterpart in standard Python.

---

`serial_clear() -> void`

 > Sends the appropriate VT-100 escape sequence to clear the screen, reset all text decoration and move the cursor to the top left position.

---

`serial_normal() -> void`

 > Sends the appropriate VT-100 escape sequence to turn off any text decoration previously requested.

---

`serial_bold() -> void`

 > Sends the appropriate VT-100 escape sequence to turn text bolding on. Subsequent text sent to the VT-100 will appear bold along with any other active decorations.

---

`serial_underline() -> void`

 > Sends the appropriate VT-100 escape sequence to turn text underlining on. Subsequent text sent to the VT-100 will appear underlined along with any other active decorations.

---

`serial_reverse() -> void`

 > Sends the appropriate VT-100 escape sequence to turn text reverse printing on. Subsequent text sent to the VT-100 will appear with the foreground and background colors reversed along with any other active decorations.

---

`serial_send(data: const[str]) -> void`

 > Sends a null-terminated string to the VT-100. This could include escape sequences or any text for display. Note that this function handles polling the remote VT-100 for XON/XOFF control flow so that it does not overwhelm a remote terminal. It also swallows any incoming escape sequences sent by the terminal. It does this because in order to detect control flow bytes it must read from the remote side. If it gets an escape sequence it must read until the sequence is done otherwise code that reads after calling `serial_send()` could end up reading part of an escape sequence and corrupting user input.

---

`serial_recv(echo_input: bool = True, mask_input: bool = False, allow_empty: bool = True) -> str`

 > Receives a null-terminated string from the VT-100. Reads from the VT-100, swallowing escape sequences and buffering any user input until the return key is pressed. Supports erasing previously-input text using the backspace key. Also supports handling XON/XOFF style control flow in the case that the VT-100 has sent us a request to stop transmitting. By default the input that is typed will be echoed to the terminal much in the same way typing on the command-line works on a modern computer. To turn that off, set the `echo_input` parameter to `False` instead of the default `True`. To echo the mask character `*` instead of the typed character, turn on `mask_input` by setting the parameter to `True` instead of the default `False`. Note that this setting has no effect if `echo_input` is `False`. If you wish to allow empty string input (pressing enter without typing anything), you can set `allow_empty` to `True`. Otherwise, the function will only let the user continue once at least one character has been typed before pressing enter.

---

`serial_input(prompt: const[str], echo_input: bool = True, mask_input: bool = False, allow_empty: bool = True) -> str:`

 > Display the prompt string `prompt` to the VT-100 before waiting for the user to enter some text and press enter. Upon pressing enter a newline will be sent to the VT-100 to place the cursor on the next line. The optional parameters `echo_input`, `mask_input` and `allow_empty` have the same functionality and default values as in `serial_recv()`.

### conversion.fixed

A library for converting fixed point decimal numbers to strings and strings to fixed point decimal numbers. MiniDragon and MiniPy both lack any floating point support and generally only work with integers. However, floating point decimals are not the only system. Fixed point decimal numbers are employed to allow working with decimal numbers in a way that is possible with the speed and hardware limitations of the MiniDragon. Along with the `fixed()` intrinsic that allows you to define decimal constants in code easily, the conversion library allows you to accept user input and convert it to a fixed point number suitable for performing math against. It also allows you to take a fixed point number and convert to the approximate decimal representation for displaying to a user.

Note that there is no math library for working with fixed point decimal numbers. That's because the math for fixed point decimal numbers works out to be compatible with existing integers. For more information, please read up on [Fixed Point Arithmetic](https://en.wikipedia.org/wiki/Fixed-point_arithmetic). However, non-bitwise math should generally work out. For instance, to add two fixed-point numbers stored in `a` and `b` with the same `fracbits` together, one would simply perform the expression `a + b`. The same thing works for subtraction, where you would perform `a - b`. Negating numbers works as expected, and negative numbers input by the user will be in the correct form for arithmetic to work out. Multipliciation is similar to how you learned to multiply on paper. The result of any multiplication needs to be shifted right by `fracbits`. So, to multiply two numbers, you would perform an expression similar to `(a * b) >> fracbits`. Division works in reverse, where you would shift left by the number of fracbits. Tricks for multiplying or dividing by a power of two using a shift operation still work the same. Note that there are concerns with loss of precision when multiplying and dividing, as well as the possibility of multiplying and dividing numbers with different `fracbits` as long as you manage your final shift correctly. For details, please read up on the wikipedia link above.

To use any of the following functions, import them using a statement in the form of `from conversion.fixed import bla` where `bla` is the function that you wish to support. Note that in order to successfully compile, the compiler will need to know where to find this library. So, you should use the compiler option `-lib /path/to/lib/` to point the compiler at the `lib/` directory included at the root of this repo.

---

`strtofixed(val: const[str], fracbits: uint8 = 8) -> int32`

 > Given a string that represents an integer or decimal number, conver it to a fixed width integer suitable for performing math against. Note that much like the `fixed()` intrinsic, this defaults to 8 fractional bits of precision, allowing you to represent down to `1/256` of decimal. If you wish to change this, you can specify another value for the `fracbits` parameter. Note that fixed width decmials do not carry any metadata with them so neither the compiler nor the conversion library will warn you if you try to convert a number with one `fracbits` value and then display it with another `fracbits`.

---

`fixedtostr(val: int32, precision: uint8, fracbits: uint8 = 8) -> str`

 > Given a fixed point decimal number and a precision, converts that number to a string suitable for display to a user. The `precision` argument is the number of digits after the decimal place. Valid values are `0`-`6` inclusive. Note that this function will round the number before display so that the rendered display is as close to correct as possible. So, if you had the number `3.75` or `3.9` and converted it to a string with `precision` set to `0`, you should expect to get back a string with the value `"4"`. Similarly if you had the number `3.01` and converted it with a `precision` of `1` you should expect to get a string back with the value `"3.0"`. If instead your number was `3.09` and you specified the same precision, you'd instead expect to get back a string with the value `"3.1"`. The same warning about `fracbits` applies. It is your responsibility to ensure that you use the same `fracbits` for all conversions and `fixed()` intrinsics if you wish for the converted numbers to be correct.

## Application Binary Interface

Since the MiniDragon ISA is stack-based with an accumulator, it should come as no surprise that function parameters, local variables, the function return and the return address are placed onto the stack. If you are looking to write functions in assembly which interop with MiniPy code it is important to respect the ABI otherwise you will most likely get a crash from stack corruption. The easiest way to conform to the interface for a given function is to simply let the compiler generate the function stub for you. Define the function with its parameters and return in a module, return a dummy value, compile it, and copy the skeleton out of the assembly listing.

The MiniDragon CPU uses a standard stack that starts at the top of memory and grows down. A push operation will decrement the PC register and then store the value at the memory location pointed at by PC. A pop operation will load the value from the memory location pointed at by PC and then increment the PC register. Function parameters are always provided on the stack even when they could fit in the A, U or V registers. They are pushed onto the stack in the order that they appear in the function definition. When a function is called, after the compiler pushes all of the parameters onto the stack, the actual call operation will push the address of the instruction after the call onto the stack as a big-endian 16 bit address and then jump to the first byte of the function. That means upon entering a function you should expect the PC register to point at the first byte of the return address in memory with the second byte in the next memory address.

It is the function's responsibility to restore all registers to their previous state upon exiting a function. The compiler does not recognize any temporary registers that are considered dirty after a function call. That means if you use a register in your function, you're required to push the value of that register onto the stack at the beginning of your function and pop the value off of the stack just before returning. This requirement exists for the `A`, `U`, `V` and `SPC` registers but does not exist for the `PC` or `IP` registers since those are expected to be modified by executing the function. Just about every useful function will end up clobbering the `A` register so it is a safe bet to assume you will be saving this register when writing any meaningful function.

When leaving a function, a ret operation is used to pop the return address from the stack and jump to it. This means that when you leave a function you are expected to have the PC register pointing at the first byte of the return address on the stack. When that return address is popped, the PC will be incremented by 2 and should point at the first byte of the return value. The calling code will expect to pop that value from the stack which should return the PC register to the location that it pointed at before any function parameters were pushed onto the stack. That means that it is the called function's responsibility to move the return address and return value when appropriate. This will be necessary when the function parameters take more space on the stack than the return value. Since the calling code expects the parameters to be "consumed" by the called function it will not attempt to pop the parameters off the stack when execution is returned to it after the ret operation.

Note that in cases where the return value takes more space on the stack than the parameters the compiler will insert padding bytes onto the stack so that the called function does not need to relocate the return pointer down the stack to make room for the return value. If the length of all parameters exactly equals or surpasses the size of the return value (or the function is a `void` return) then no padding will be inserted. If you do not want this and you are willing to relocate the return value and return pointer on the stack even when padding bytes could be inserted for you, you can use the `nopad[]` modifier on the function's return type. Using `nopad[]` will instruct the compiler not to insert padding bytes under any circumstance and you will be responsible for moving the return pointer as well as locating the return value on the stack manually.

Examples of functions as well as both their just-after-call and their just-before-return stack layout are shown below. An arbitrary stack address of `0xBEE5` has been chosen as the location of `PC` just prior to the function parameters being pladed onto the stack. The stack is presented where the highest value on the screen is also the highest memory address.

---

`def fun() -> void: ...`

The stack on the first instruction of the function as well as the stack just before returning looks like the following. `PC` should be set to `0xBEE3` both in the first instruction and just prior to returning from the function.

| Memory Location | Description |
| --- | --- |
| `0xBEE4` | low byte of return address  |
| `0xBEE3` | high byte of return address |

---

`def fun(p1: int8, p2: int16) -> void: ...`

The stack on the first instruction of the function looks like the following. Note that `PC` should be set to `0xBEE0` when your function starts executing.

| Memory Location | Description |
| --- | --- |
| `0xBEE4` | parameter p1 |
| `0xBEE3` | low byte of parameter p2 |
| `0xBEE2` | high byte of parameter p2 |
| `0xBEE1` | low byte of return address  |
| `0xBEE0` | high byte of return address |

You are responsible for making sure the stack looks like the following before returning by moving the return address. Note that `PC` should point to `0xBEE3` just prior to returning.

| Memory Location | Description |
| --- | --- |
| `0xBEE4` | low byte of return address  |
| `0xBEE3` | high byte of return address |

---

`def fun() -> int8: ...`

The stack on the first instruction of the function looks like the following. Note the padding byte the compiler inserts so you have room for the return value. Note that `PC` should be set to `0xBEE2` when your function starts executing.

| Memory Location | Description |
| --- | --- |
| `0xBEE4` | padding byte for function return |
| `0xBEE3` | low byte of return address |
| `0xBEE2` | high byte of return address |

The stack should look like the following just before returning. Note that `PC` should point to `0xBEE2` just before executing the return instruction.

| Memory Location | Description |
| --- | --- |
| `0xBEE4` | function return value |
| `0xBEE3` | low byte of return address  |
| `0xBEE2` | high byte of return address |

---

`def fun() -> nopad[int16]: ...`

The stack on the first instruction of the function looks like the following. Note that the compiler was told not to insert padding, so you are responsible for relocating the return address to make room for the function return. Note that `PC` should be set to `0xBEE3` when your function starts executing.

| Memory Location | Description |
| --- | --- |
| `0xBEE4` | low byte of return address |
| `0xBEE3` | high byte of return address |

The stack should look like the following just before returning. You are responsible for moving the return address to make room for the return value. Note that `PC` should point to `0xBEE1` just before executing the return instruction.

| Memory Location | Description |
| --- | --- |
| `0xBEE4` | function return value low byte  |
| `0xBEE3` | function return value high byte |
| `0xBEE2` | low byte of return address |
| `0xBEE1` | high byte of return address |

## Compiler Optimizations

Regardless of whether the optimize code flag has been passed to the compiler, the compiler will attempt to evaluate any constants found in the code it is compiling. That means if you have an expression whose value is known at compile-time, the compiler will not emit code to calculate that expression. Instead, the value of that expression as calculated at compile time will be inserted into the compiled assembly listing instead. The compiler is aware of global and local constants which are known at compile time in its evaluation of whole or partial expressions that can be optimized to a single value.

Additionally, when the compiler has been instructed to do so with the optimize flag (`-z` or `--optimize`) it will make passes over the assembly that it produces until it can no longer find optimizations to perform. This usually results in code that is smaller and runs faster but has the potential to accidentally emit incorrect code. Care has been taken to only perform optimizations that are provably safe and do not alter the semantics of the code at all. However, since compiler optimization passes are effectively pattern matching heuristics, it is possible that the compiler may get things wrong. The compiler will look for things such as redundant loads and stores, redundant stack moving operations, groups of instructions that are performed simply to check the zero or carry flag which can be reduced to equivalent smaller groups, conditional jumps based on constants and redundant stack operations when immediate operations could be substituted.

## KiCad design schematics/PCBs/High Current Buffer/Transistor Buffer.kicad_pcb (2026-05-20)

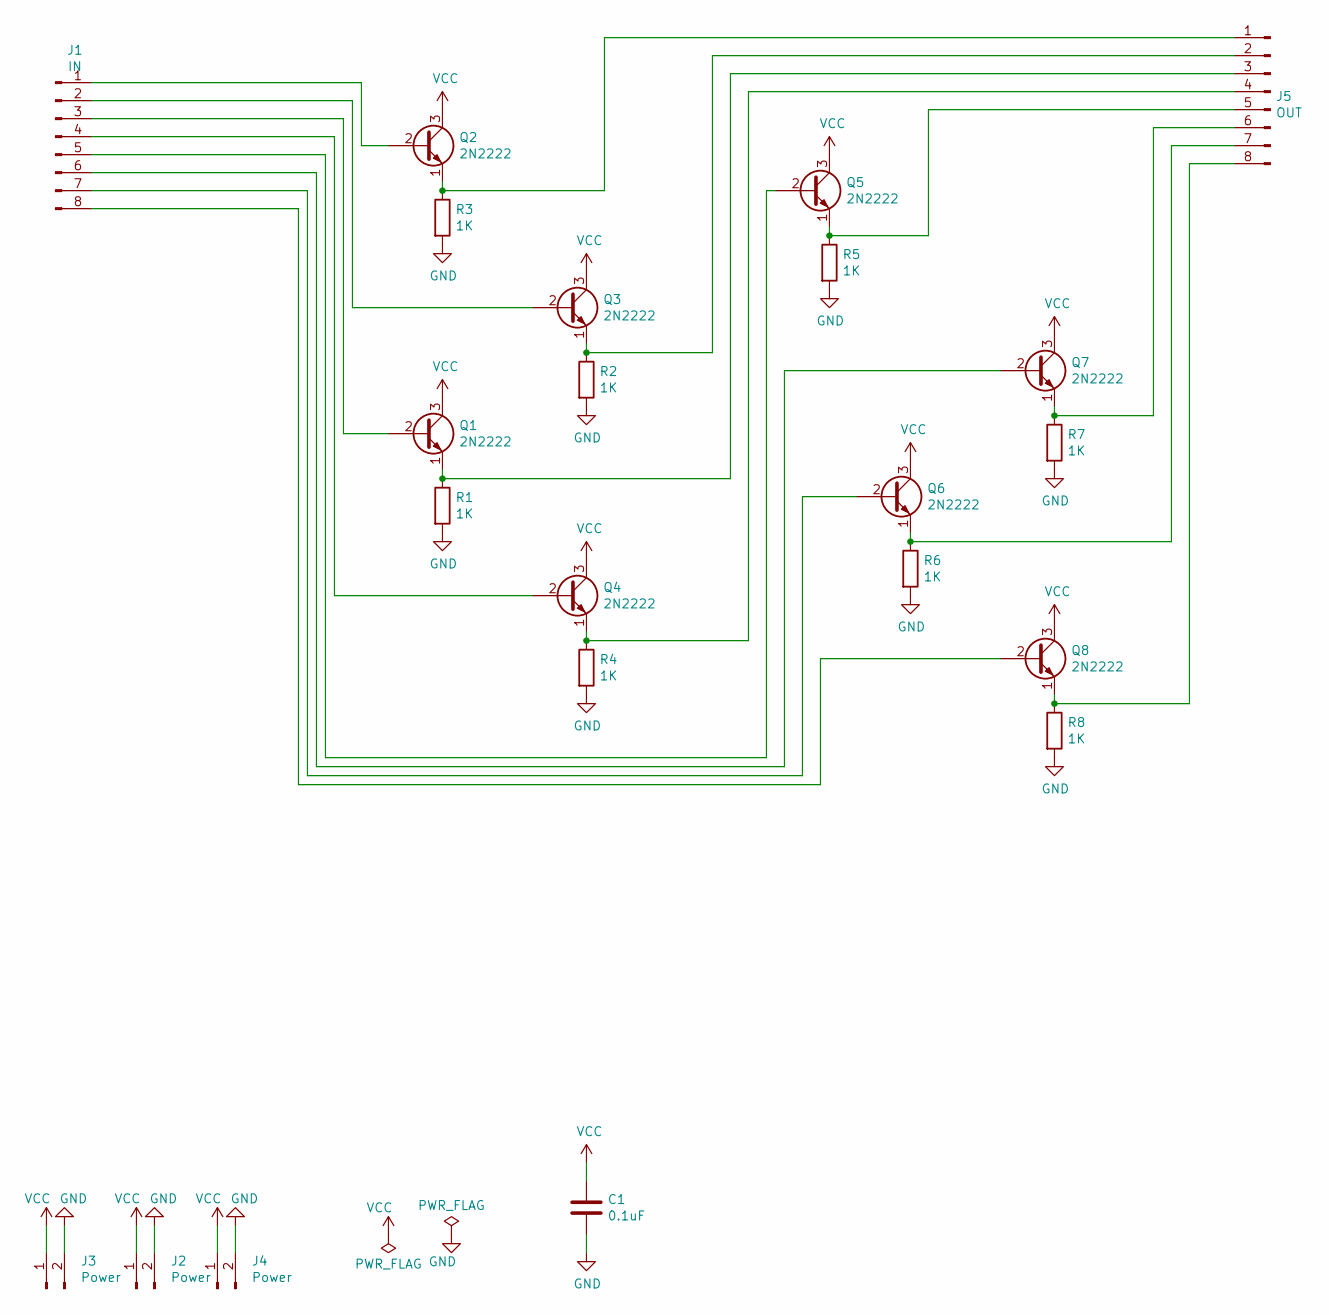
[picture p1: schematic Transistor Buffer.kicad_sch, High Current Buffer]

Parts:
C1: 0.1uF; C_Disc_D4.3mm_W1.9mm_P5.00mm
J1: IN; PinHeader_1x08_P2.54mm_Vertical
J2, J3, J4: Power; PinHeader_1x02_P2.54mm_Vertical
J5: OUT; PinHeader_1x08_P2.54mm_Vertical
Q1, Q2, Q3, Q4, Q5, Q6, Q7, Q8: 2N2222; TO-92_Inline
R1, R2, R3, R4, R5, R6, R7, R8: 1K; R_Axial_DIN0309_L9.0mm_D3.2mm_P12.70mm_Horizontal

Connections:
GND: C1.2, J2.2, J3.2, J4.2, R1.2, R2.2, R3.2, R4.2, R5.2, R6.2, R7.2, R8.2
unnamed: J1.1, Q2.2 (B)
unnamed: J1.2, Q3.2 (B)
unnamed: J1.3, Q1.2 (B)
unnamed: J1.4, Q4.2 (B)
unnamed: J1.5, Q5.2 (B)
unnamed: J1.6, Q7.2 (B)
unnamed: J1.7, Q6.2 (B)
unnamed: J1.8, Q8.2 (B)
unnamed: J5.1, Q2.1 (E), R3.1
unnamed: J5.2, Q3.1 (E), R2.1
unnamed: J5.3, Q1.1 (E), R1.1
unnamed: J5.4, Q4.1 (E), R4.1
unnamed: J5.5, Q5.1 (E), R5.1
unnamed: J5.6, Q7.1 (E), R7.1
unnamed: J5.7, Q6.1 (E), R6.1
unnamed: J5.8, Q8.1 (E), R8.1
VCC: C1.1, J2.1, J3.1, J4.1, Q1.3 (C), Q2.3 (C), Q3.3 (C), Q4.3 (C), Q5.3 (C), Q6.3 (C), Q7.3 (C), Q8.3 (C)

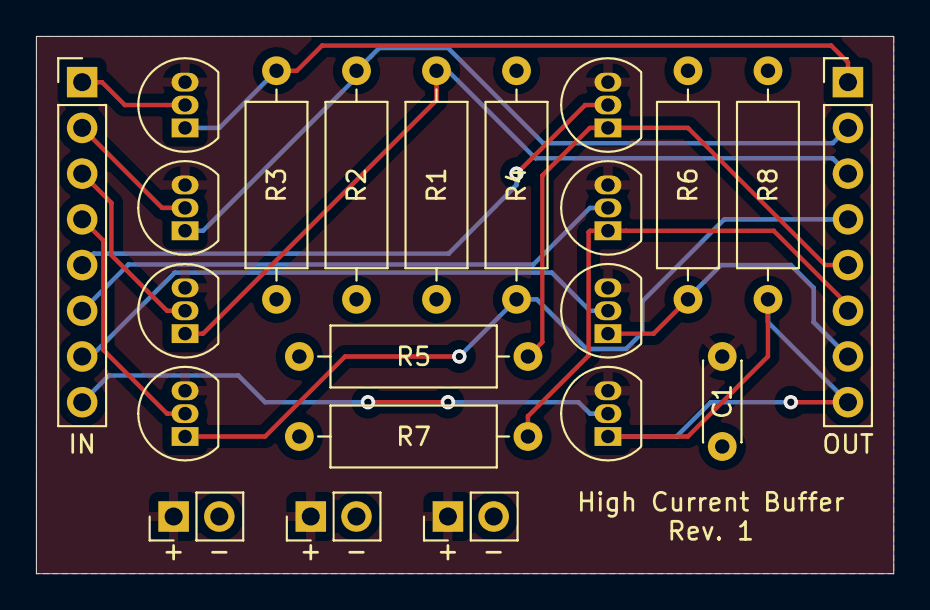
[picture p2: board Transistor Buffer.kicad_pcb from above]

Board: 2 copper layers, 47.6 x 29.8 mm, 22 parts (0 on the bottom side), 18 nets.

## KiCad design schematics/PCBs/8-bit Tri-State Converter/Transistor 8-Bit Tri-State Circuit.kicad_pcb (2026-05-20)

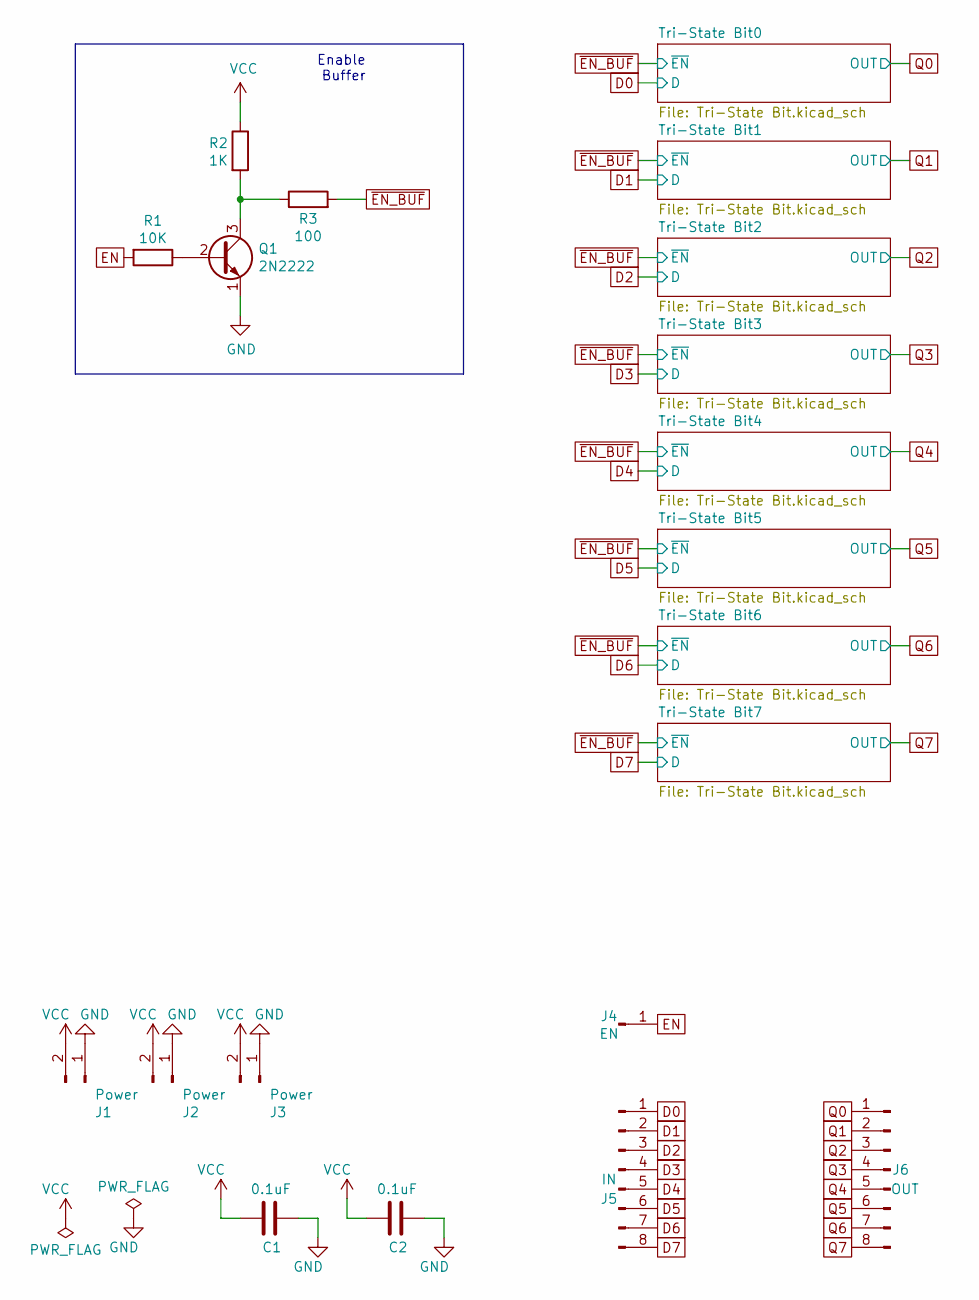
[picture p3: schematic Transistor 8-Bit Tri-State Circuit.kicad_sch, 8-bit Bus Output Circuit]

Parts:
C1, C2: 0.1uF; C_Disc_D4.3mm_W1.9mm_P5.00mm
J1, J2, J3: Power; PinHeader_1x02_P2.54mm_Vertical
J4: EN; PinHeader_1x01_P2.54mm_Vertical
J5: IN; PinHeader_1x08_P2.54mm_Vertical
J6: OUT; PinHeader_1x08_P2.54mm_Vertical
Q1: 2N2222; TO-92_Inline
R1: 10K; R_Axial_DIN0309_L9.0mm_D3.2mm_P12.70mm_Horizontal
R2: 1K; R_Axial_DIN0309_L9.0mm_D3.2mm_P12.70mm_Horizontal
R3: 100; R_Axial_DIN0309_L9.0mm_D3.2mm_P12.70mm_Horizontal

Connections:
D0: J5.1; also elsewhere on the board
D1: J5.2; also elsewhere on the board
D2: J5.3; also elsewhere on the board
D3: J5.4; also elsewhere on the board
D4: J5.5; also elsewhere on the board
D5: J5.6; also elsewhere on the board
D6: J5.7; also elsewhere on the board
D7: J5.8; also elsewhere on the board
EN: J4.1, R1.2
GND: C1.1, C2.1, J1.1, J2.1, J3.1, Q1.1 (E); also elsewhere on the board
unnamed: Q1.2 (B), R1.1
unnamed: Q1.3 (C), R2.2, R3.1
Q0: J6.1; also elsewhere on the board
Q1: J6.2; also elsewhere on the board
Q2: J6.3; also elsewhere on the board
Q3: J6.4; also elsewhere on the board
Q4: J6.5; also elsewhere on the board
Q5: J6.6; also elsewhere on the board
Q6: J6.7; also elsewhere on the board
Q7: J6.8; also elsewhere on the board
VCC: C1.2, C2.2, J1.2, J2.2, J3.2, R2.1; also elsewhere on the board
~EN_BUF: R3.2; also elsewhere on the board

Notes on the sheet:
Enable Buffer

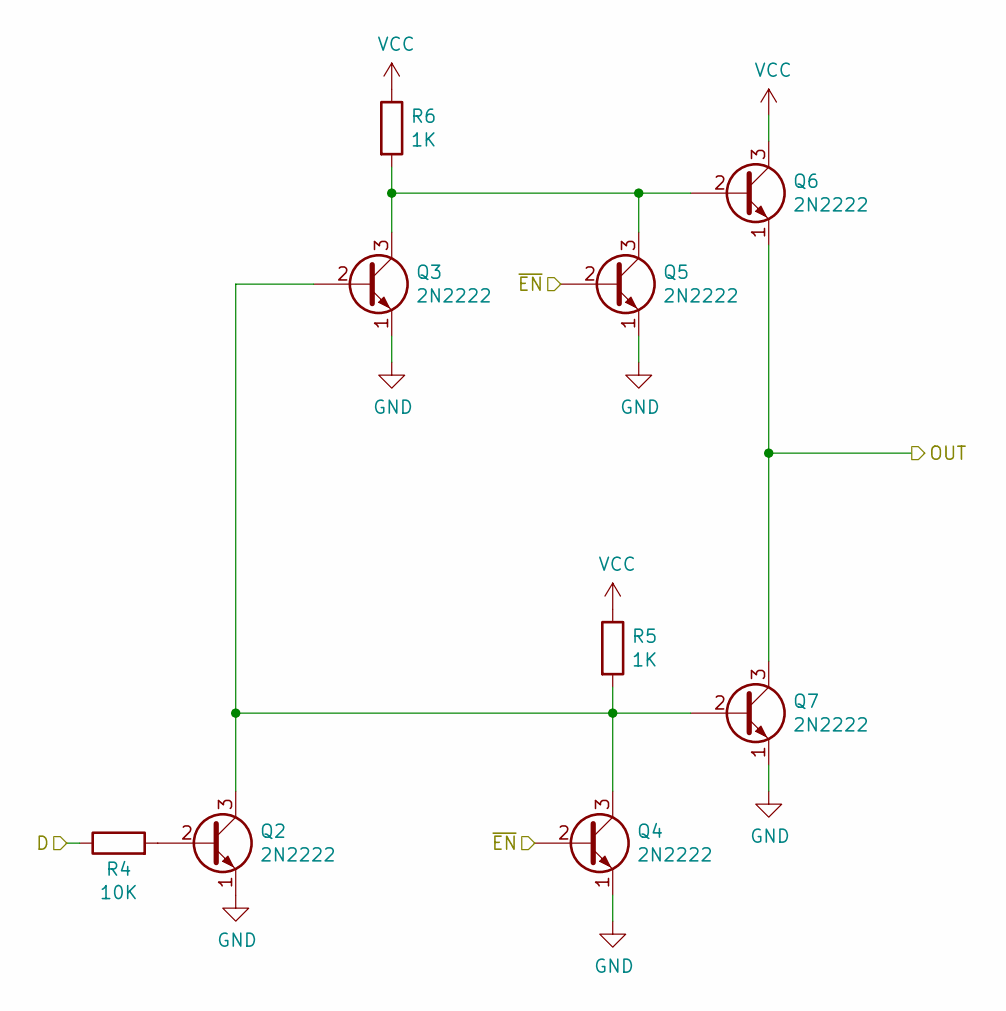
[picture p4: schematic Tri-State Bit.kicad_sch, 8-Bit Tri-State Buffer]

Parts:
Q2, Q3, Q4, Q5, Q6, Q7: 2N2222; TO-92_Inline
R4: 10K; R_Axial_DIN0309_L9.0mm_D3.2mm_P12.70mm_Horizontal
R5, R6: 1K; R_Axial_DIN0309_L9.0mm_D3.2mm_P12.70mm_Horizontal

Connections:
D0: R4.1; also elsewhere on the board
GND: Q2.1 (E), Q3.1 (E), Q4.1 (E), Q5.1 (E), Q7.1 (E); also elsewhere on the board
unnamed: Q2.2 (B), R4.2
unnamed: Q2.3 (C), Q3.2 (B), Q4.3 (C), Q7.2 (B), R5.2
unnamed: Q3.3 (C), Q5.3 (C), Q6.2 (B), R6.2
Q0: Q6.1 (E), Q7.3 (C); also elsewhere on the board
VCC: Q6.3 (C), R5.1, R6.1; also elsewhere on the board
~EN_BUF: Q4.2 (B), Q5.2 (B); also elsewhere on the board

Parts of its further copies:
Q8, Q9, Q10, Q11, Q12, Q13, Q14, Q15, Q16, Q17, Q18, Q19, Q20, Q21, Q22, Q23, Q24, Q25, Q26, Q27, Q28, Q29, Q30, Q31, Q32, Q33, Q34, Q35, Q36, Q37, Q38, Q39, Q40, Q41, Q42, Q43, Q44, Q45, Q46, Q47, Q48, Q49: 2N2222; TO-92_Inline
R7, R10, R13, R16, R19, R22, R25: 10K; R_Axial_DIN0309_L9.0mm_D3.2mm_P12.70mm_Horizontal
R8, R9, R11, R12, R14, R15, R17, R18, R20, R21, R23, R24, R26, R27: 1K; R_Axial_DIN0309_L9.0mm_D3.2mm_P12.70mm_Horizontal

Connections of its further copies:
D1: R7.1; also elsewhere on the board
D2: R10.1; also elsewhere on the board
D3: R13.1; also elsewhere on the board
D4: R16.1; also elsewhere on the board
D5: R19.1; also elsewhere on the board
D6: R22.1; also elsewhere on the board
D7: R25.1; also elsewhere on the board
GND: Q8.1 (E), Q9.1 (E), Q10.1 (E), Q11.1 (E), Q13.1 (E), Q14.1 (E), Q15.1 (E), Q16.1 (E), Q17.1 (E), Q19.1 (E), Q20.1 (E), Q21.1 (E), Q22.1 (E), Q23.1 (E), Q25.1 (E), Q26.1 (E), Q27.1 (E), Q28.1 (E), Q29.1 (E), Q31.1 (E), Q32.1 (E), Q33.1 (E), Q34.1 (E), Q35.1 (E), Q37.1 (E), Q38.1 (E), Q39.1 (E), Q40.1 (E), Q41.1 (E), Q43.1 (E), Q44.1 (E), Q45.1 (E), Q46.1 (E), Q47.1 (E), Q49.1 (E); also elsewhere on the board
unnamed: Q8.2 (B), R7.2
unnamed: Q8.3 (C), Q9.2 (B), Q10.3 (C), Q13.2 (B), R8.2
unnamed: Q9.3 (C), Q11.3 (C), Q12.2 (B), R9.2
unnamed: Q14.2 (B), R10.2
unnamed: Q14.3 (C), Q15.2 (B), Q16.3 (C), Q19.2 (B), R11.2
unnamed: Q15.3 (C), Q17.3 (C), Q18.2 (B), R12.2
unnamed: Q20.2 (B), R13.2
unnamed: Q20.3 (C), Q21.2 (B), Q22.3 (C), Q25.2 (B), R14.2
unnamed: Q21.3 (C), Q23.3 (C), Q24.2 (B), R15.2
unnamed: Q26.2 (B), R16.2
unnamed: Q26.3 (C), Q27.2 (B), Q28.3 (C), Q31.2 (B), R17.2
unnamed: Q27.3 (C), Q29.3 (C), Q30.2 (B), R18.2
unnamed: Q32.2 (B), R19.2
unnamed: Q32.3 (C), Q33.2 (B), Q34.3 (C), Q37.2 (B), R20.2
unnamed: Q33.3 (C), Q35.3 (C), Q36.2 (B), R21.2
unnamed: Q38.2 (B), R22.2
unnamed: Q38.3 (C), Q39.2 (B), Q40.3 (C), Q43.2 (B), R23.2
unnamed: Q39.3 (C), Q41.3 (C), Q42.2 (B), R24.2
unnamed: Q44.2 (B), R25.2
unnamed: Q44.3 (C), Q45.2 (B), Q46.3 (C), Q49.2 (B), R26.2
unnamed: Q45.3 (C), Q47.3 (C), Q48.2 (B), R27.2
Q1: Q12.1 (E), Q13.3 (C); also elsewhere on the board
Q2: Q18.1 (E), Q19.3 (C); also elsewhere on the board
Q3: Q24.1 (E), Q25.3 (C); also elsewhere on the board
Q4: Q30.1 (E), Q31.3 (C); also elsewhere on the board
Q5: Q36.1 (E), Q37.3 (C); also elsewhere on the board
Q6: Q42.1 (E), Q43.3 (C); also elsewhere on the board
Q7: Q48.1 (E), Q49.3 (C); also elsewhere on the board
VCC: Q12.3 (C), Q18.3 (C), Q24.3 (C), Q30.3 (C), Q36.3 (C), Q42.3 (C), Q48.3 (C), R8.1, R9.1, R11.1, R12.1, R14.1, R15.1, R17.1, R18.1, R20.1, R21.1, R23.1, R24.1, R26.1, R27.1; also elsewhere on the board
~EN_BUF: Q10.2 (B), Q11.2 (B), Q16.2 (B), Q17.2 (B), Q22.2 (B), Q23.2 (B), Q28.2 (B), Q29.2 (B), Q34.2 (B), Q35.2 (B), Q40.2 (B), Q41.2 (B), Q46.2 (B), Q47.2 (B); also elsewhere on the board

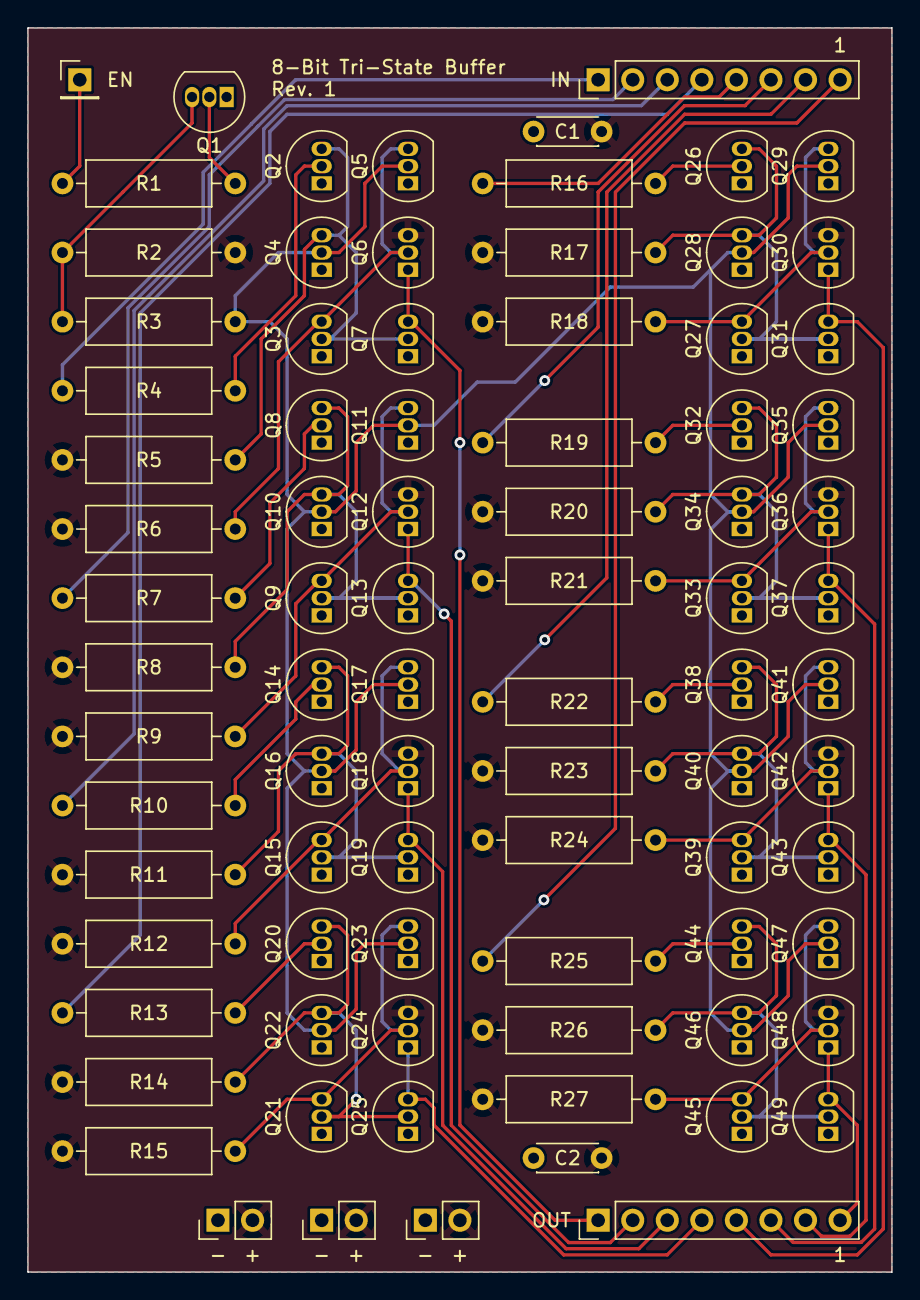
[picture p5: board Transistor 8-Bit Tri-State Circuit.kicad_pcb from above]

Board: 2 copper layers, 63.5 x 91.4 mm, 84 parts (0 on the bottom side), 46 nets.

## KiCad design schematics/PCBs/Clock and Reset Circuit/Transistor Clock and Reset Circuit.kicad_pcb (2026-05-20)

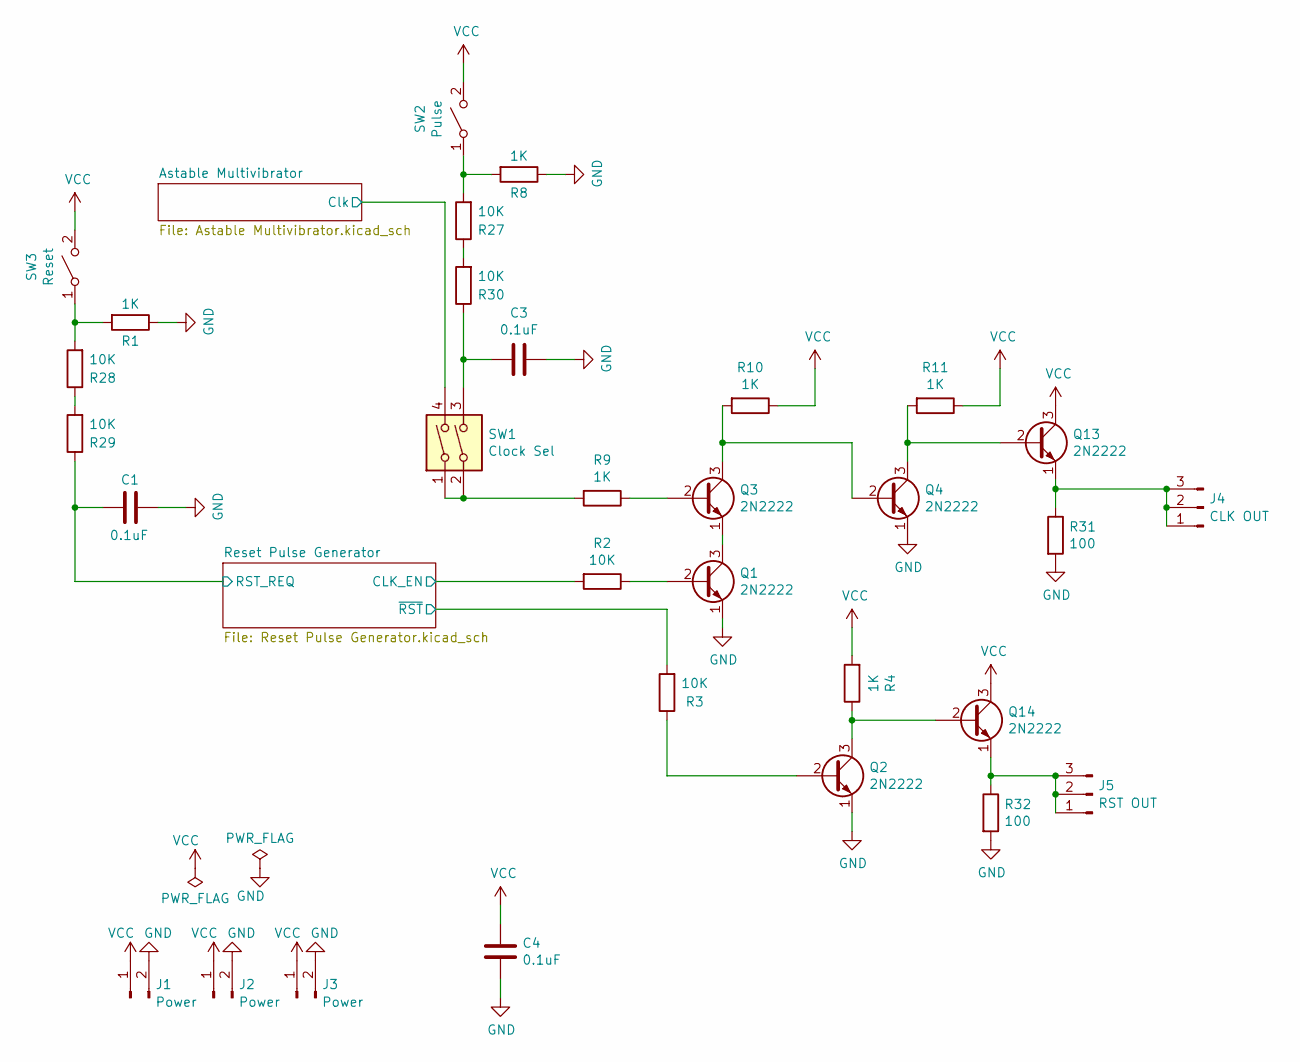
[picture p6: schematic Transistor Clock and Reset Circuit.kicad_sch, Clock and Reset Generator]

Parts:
C1, C3, C4: 0.1uF; C_Disc_D4.3mm_W1.9mm_P5.00mm
J1, J2, J3: Power; PinHeader_1x02_P2.54mm_Vertical
J4: CLK OUT; PinHeader_1x03_P2.54mm_Vertical
J5: RST OUT; PinHeader_1x03_P2.54mm_Vertical
Q1, Q2, Q3, Q4, Q13, Q14: 2N2222; TO-92_Inline
R1, R4, R8, R9, R10, R11: 1K; R_Axial_DIN0309_L9.0mm_D3.2mm_P12.70mm_Horizontal
R2, R3, R27, R28, R29, R30: 10K; R_Axial_DIN0309_L9.0mm_D3.2mm_P12.70mm_Horizontal
R31, R32: 100; R_Axial_DIN0309_L9.0mm_D3.2mm_P12.70mm_Horizontal
SW1: Clock Sel; SW_DIP_SPSTx02_Slide_9.78x7.26mm_W7.62mm_P2.54mm
SW2: Pulse; SW_PUSH_6mm_H5mm
SW3: Reset; SW_PUSH_6mm_H5mm

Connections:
/Astable Multivibrator/Clk: SW1.4; also elsewhere on the board
/Reset Pulse Generator/CLK_EN: R2.2; also elsewhere on the board
/Reset Pulse Generator/RST_REQ: C1.1, R29.1; also elsewhere on the board
/Reset Pulse Generator/~RST: R3.2; also elsewhere on the board
GND: C1.2, C3.1, C4.2, J1.2, J2.2, J3.2, Q1.1 (E), Q2.1 (E), Q4.1 (E), R1.1, R8.1, R31.2, R32.2; also elsewhere on the board
unnamed: C3.2, R30.1, SW1.3
unnamed: J4.1, J4.2, J4.3, Q13.1 (E), R31.1
unnamed: J5.1, J5.2, J5.3, Q14.1 (E), R32.1
unnamed: Q1.2 (B), R2.1
unnamed: Q1.3 (C), Q3.1 (E)
unnamed: Q2.2 (B), R3.1
unnamed: Q3.2 (B), R9.1
unnamed: Q3.3 (C), Q4.2 (B), R10.2
unnamed: Q4.3 (C), Q13.2 (B), R11.2
unnamed: Q2.3 (C), Q14.2 (B), R4.1
unnamed: R9.2, SW1.1, SW1.2
unnamed: R27.1, R30.2
unnamed: R28.1, R29.2
unnamed: R8.2, R27.2, SW2.1 (A)
unnamed: R1.2, R28.2, SW3.1 (A)
VCC: C4.1, J1.1, J2.1, J3.1, Q13.3 (C), Q14.3 (C), R4.2, R10.1, R11.1, SW2.2 (B), SW3.2 (B); also elsewhere on the board

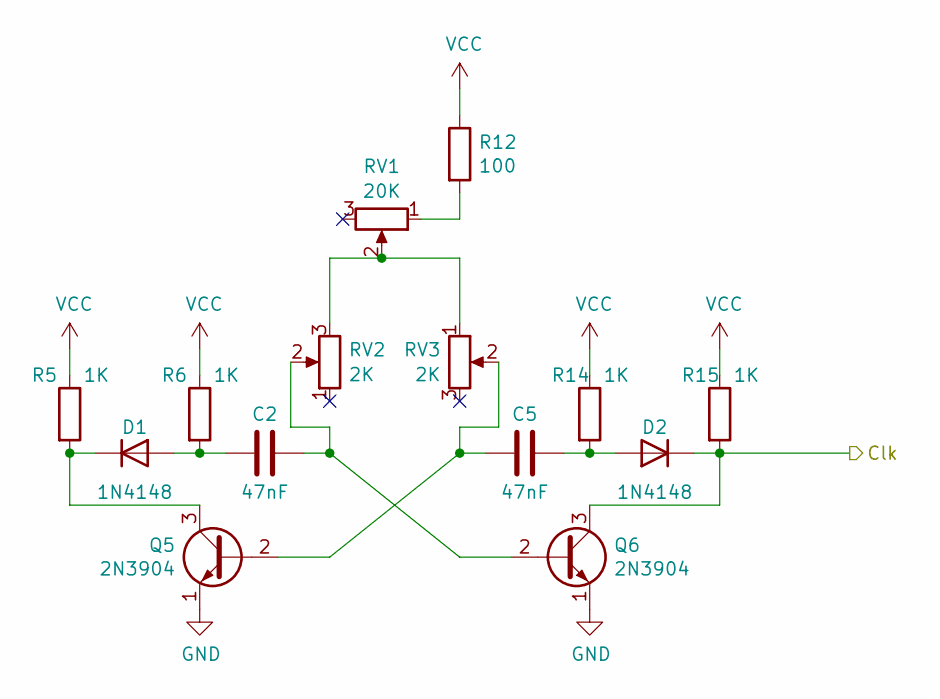
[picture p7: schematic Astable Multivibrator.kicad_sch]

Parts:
C2, C5: 47nF; C_Disc_D4.3mm_W1.9mm_P5.00mm
D1, D2: 1N4148; D_DO-35_SOD27_P7.62mm_Horizontal
Q5, Q6: 2N3904; TO-92_Inline
R5, R6, R14, R15: 1K; R_Axial_DIN0309_L9.0mm_D3.2mm_P12.70mm_Horizontal
R12: 100; R_Axial_DIN0309_L9.0mm_D3.2mm_P12.70mm_Horizontal
RV1: 20K; Potentiometer_ACP_CA9-H5_Horizontal
RV2, RV3: 2K; Potentiometer_ACP_CA9-H5_Horizontal

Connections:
/Astable Multivibrator/Clk: D2.1 (K), Q6.3 (C), R15.2; also elsewhere on the board
GND: Q5.1 (E), Q6.1 (E); also elsewhere on the board
unnamed: C2.2, D1.2 (A), R6.2
unnamed: D1.1 (K), Q5.3 (C), R5.2
unnamed: C5.1, D2.2 (A), R14.2
unnamed: C5.2, Q5.2 (B), RV3.2
unnamed: C2.1, Q6.2 (B), RV2.2
unnamed: R12.2, RV1.1
unnamed: RV1.2, RV2.3, RV3.1
VCC: R5.1, R6.1, R12.1, R14.1, R15.1; also elsewhere on the board

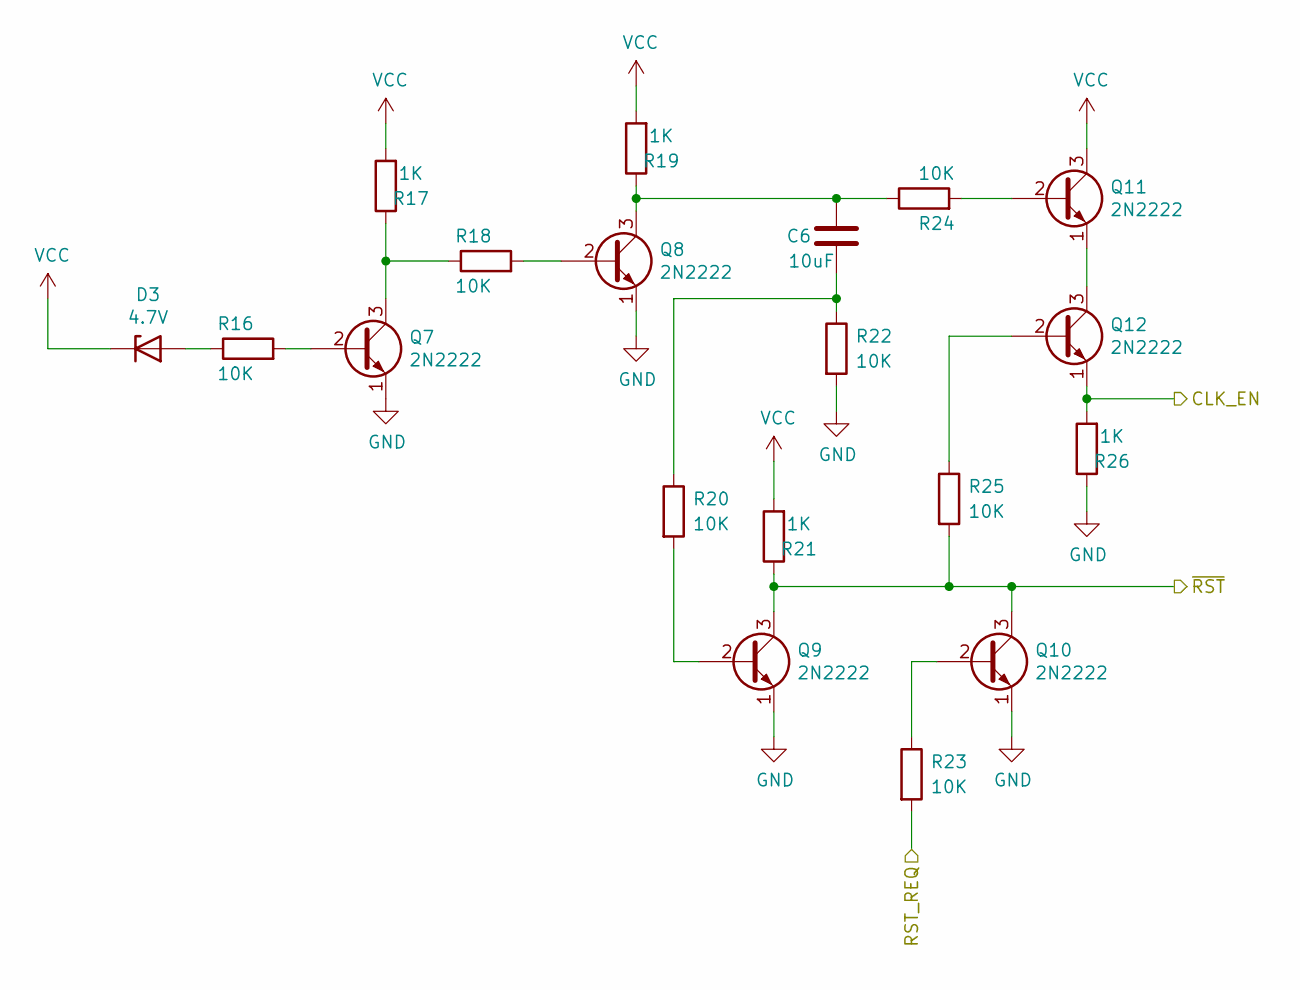
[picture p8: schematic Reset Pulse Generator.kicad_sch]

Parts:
C6: 10uF; C_Disc_D4.3mm_W1.9mm_P5.00mm
D3: 4.7V; D_DO-35_SOD27_P7.62mm_Horizontal
Q7, Q8, Q9, Q10, Q11, Q12: 2N2222; TO-92_Inline
R16, R18, R20, R22, R23, R24, R25: 10K; R_Axial_DIN0309_L9.0mm_D3.2mm_P12.70mm_Horizontal
R17, R19, R21, R26: 1K; R_Axial_DIN0309_L9.0mm_D3.2mm_P12.70mm_Horizontal

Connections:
/Reset Pulse Generator/CLK_EN: Q12.1 (E), R26.2; also elsewhere on the board
/Reset Pulse Generator/RST_REQ: R23.2; also elsewhere on the board
/Reset Pulse Generator/~RST: Q9.3 (C), Q10.3 (C), R21.1, R25.2; also elsewhere on the board
GND: Q7.1 (E), Q8.1 (E), Q9.1 (E), Q10.1 (E), R22.2, R26.1; also elsewhere on the board
unnamed: C6.2, R20.1, R22.1
unnamed: D3.2 (A), R16.1
unnamed: Q7.2 (B), R16.2
unnamed: Q7.3 (C), R17.1, R18.1
unnamed: Q8.2 (B), R18.2
unnamed: C6.1, Q8.3 (C), R19.1, R24.1
unnamed: Q9.2 (B), R20.2
unnamed: Q10.2 (B), R23.1
unnamed: Q11.2 (B), R24.2
unnamed: Q11.1 (E), Q12.3 (C)
unnamed: Q12.2 (B), R25.1
VCC: D3.1 (K), Q11.3 (C), R17.2, R19.2, R21.2; also elsewhere on the board

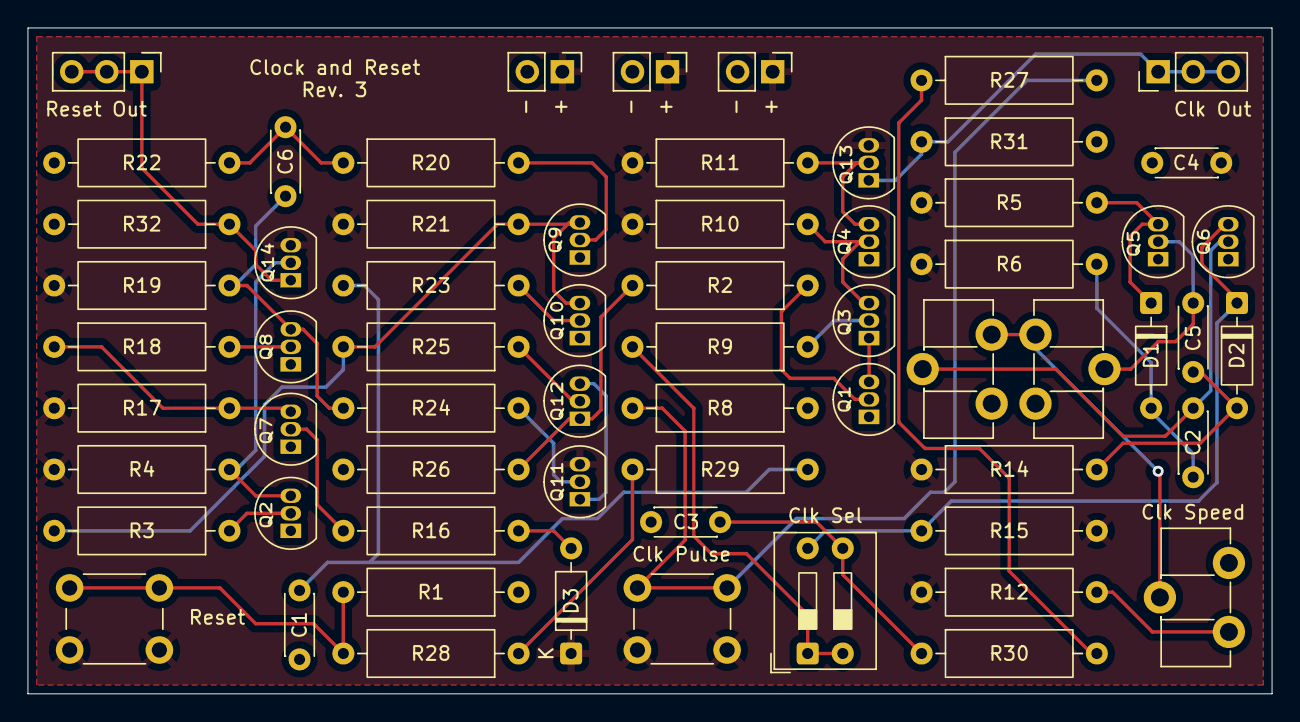
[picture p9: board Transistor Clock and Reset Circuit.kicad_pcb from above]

Board: 2 copper layers, 90.2 x 48.3 mm, 64 parts (0 on the bottom side), 39 nets.

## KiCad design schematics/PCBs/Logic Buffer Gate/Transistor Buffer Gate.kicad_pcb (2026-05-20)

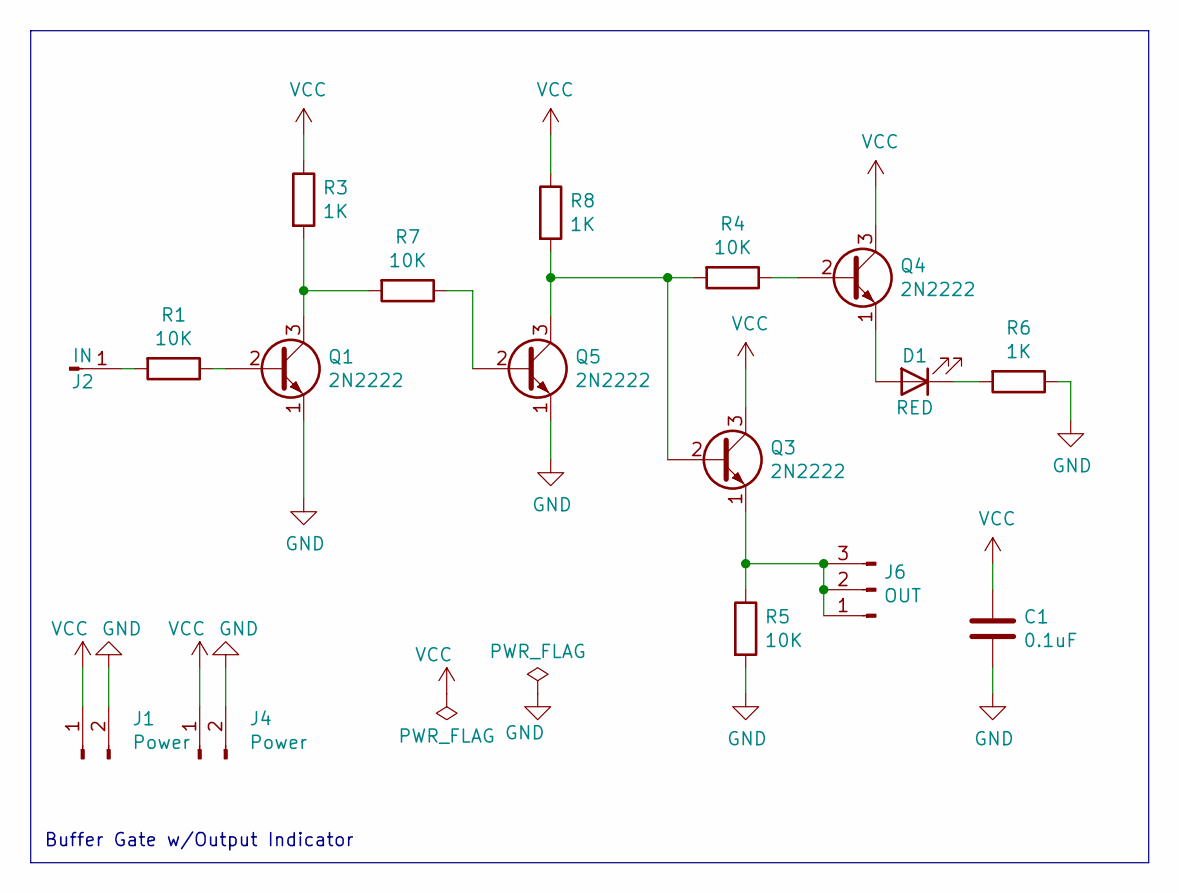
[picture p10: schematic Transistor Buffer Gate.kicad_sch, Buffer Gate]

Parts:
C1: 0.1uF; C_Disc_D4.3mm_W1.9mm_P5.00mm
D1: RED; LED_D5.0mm
J1, J4: Power; PinHeader_1x02_P2.54mm_Vertical
J2: IN; PinHeader_1x01_P2.54mm_Vertical
J6: OUT; PinHeader_1x03_P2.54mm_Vertical
Q1, Q3, Q4, Q5: 2N2222; TO-92_Inline
R1, R4, R5, R7: 10K; R_Axial_DIN0309_L9.0mm_D3.2mm_P12.70mm_Horizontal
R3, R6, R8: 1K; R_Axial_DIN0309_L9.0mm_D3.2mm_P12.70mm_Horizontal

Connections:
GND: C1.2, J1.2, J4.2, Q1.1 (E), Q5.1 (E), R5.2, R6.1
unnamed: D1.2 (A), Q4.1 (E)
unnamed: D1.1 (K), R6.2
unnamed: J2.1, R1.2
unnamed: J6.1, J6.2, J6.3, Q3.1 (E), R5.1
unnamed: Q1.2 (B), R1.1
unnamed: Q1.3 (C), R3.2, R7.2
unnamed: Q3.2 (B), Q5.3 (C), R4.2, R8.2
unnamed: Q4.2 (B), R4.1
unnamed: Q5.2 (B), R7.1
VCC: C1.1, J1.1, J4.1, Q3.3 (C), Q4.3 (C), R3.1, R8.1

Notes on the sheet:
Buffer Gate w/Output Indicator

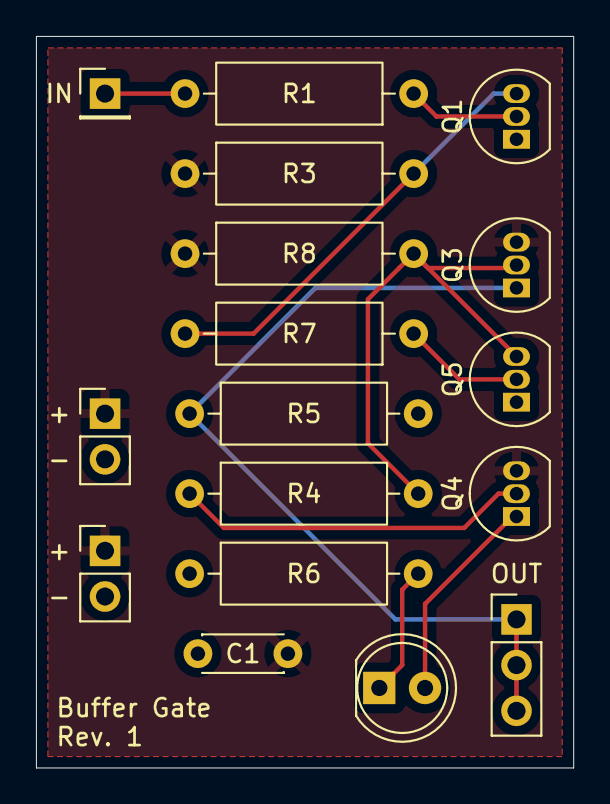
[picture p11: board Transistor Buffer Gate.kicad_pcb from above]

Board: 2 copper layers, 29.8 x 40.6 mm, 17 parts (0 on the bottom side), 11 nets.

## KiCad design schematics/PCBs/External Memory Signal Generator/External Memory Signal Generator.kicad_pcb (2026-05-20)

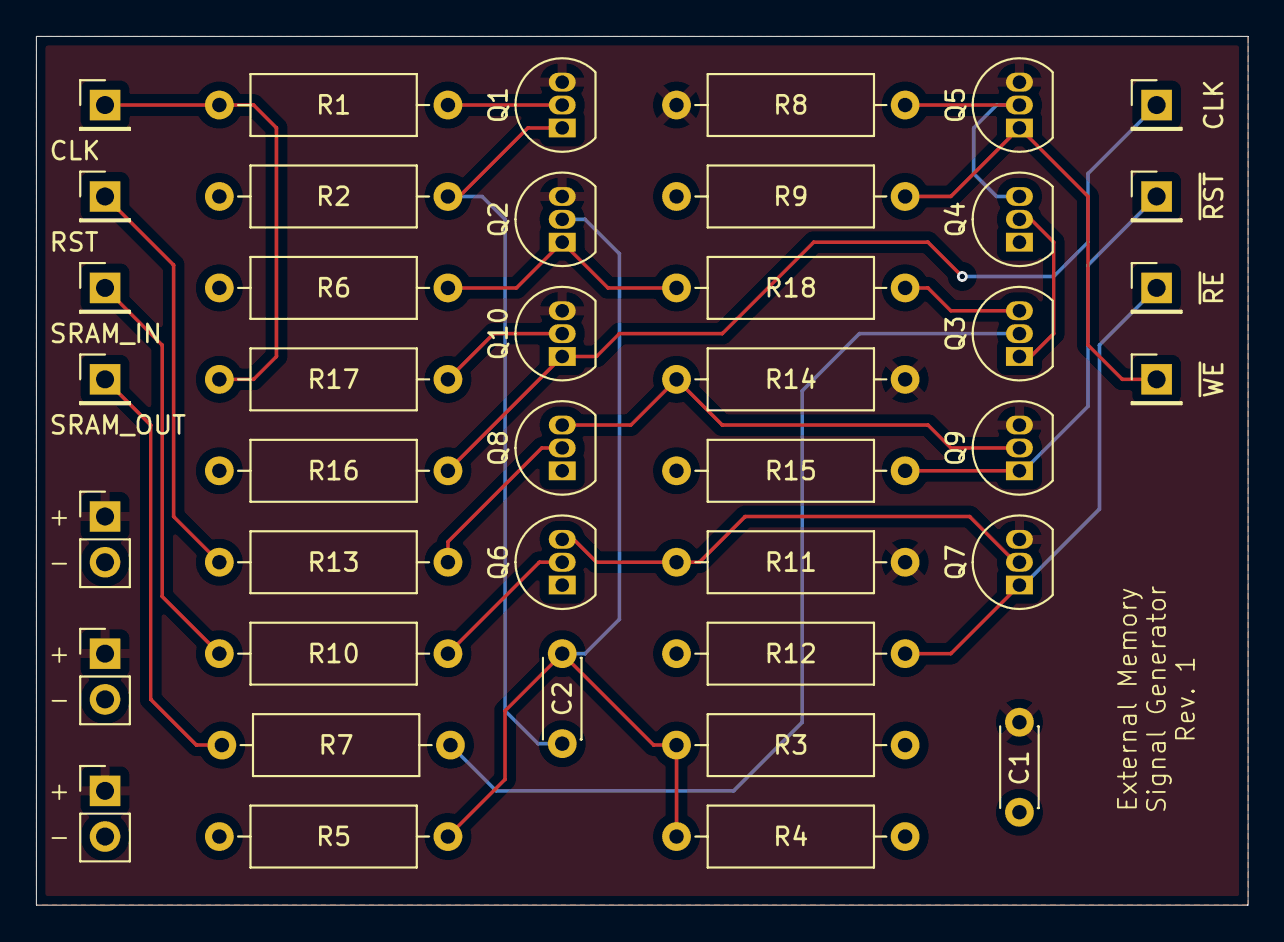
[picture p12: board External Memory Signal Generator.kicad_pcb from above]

Board: 2 copper layers, 67.3 x 48.3 mm, 41 parts (0 on the bottom side), 23 nets.

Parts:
C1, C2: 0.1uF; C_Disc_D4.3mm_W1.9mm_P5.00mm
J1, J11: CLK; PinHeader_1x01_P2.54mm_Vertical
J2: RST; PinHeader_1x01_P2.54mm_Vertical
J3: SRAM_IN; PinHeader_1x01_P2.54mm_Vertical
J4: SRAM_OUT; PinHeader_1x01_P2.54mm_Vertical
J5: ~{WE}; PinHeader_1x01_P2.54mm_Vertical
J6, J7, J8: Power; PinHeader_1x02_P2.54mm_Vertical
J9: ~{RE}; PinHeader_1x01_P2.54mm_Vertical
J10: ~{RST}; PinHeader_1x01_P2.54mm_Vertical
Q1, Q2, Q3, Q4, Q5, Q6, Q7, Q8, Q9, Q10: 2N2222; TO-92_Inline
R1, R6, R8, R11, R14, R17: 1K; R_Axial_DIN0309_L9.0mm_D3.2mm_P12.70mm_Horizontal
R2, R3, R4, R5, R9, R12, R15, R16, R18: 100; R_Axial_DIN0309_L9.0mm_D3.2mm_P12.70mm_Horizontal
R7, R10, R13: 10K; R_Axial_DIN0309_L9.0mm_D3.2mm_P12.70mm_Horizontal

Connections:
/CLK: J1.1, R1.2, R17.2
/CLOCK: J11.1, Q10.1 (E), R16.1
/RST: J2.1, R13.2
/SRAM_IN: J3.1, R10.2
/SRAM_OUT: J4.1, R7.2
/~RESET: J10.1, Q9.1 (E), R15.1
/~RE: J9.1, Q7.1 (E), R12.1
/~WE: J5.1, Q5.1 (E), R9.1
GND: C1.1, J6.2, J7.2, J8.2, Q4.1 (E), Q6.1 (E), Q8.1 (E), R2.2, R3.2, R4.2, R5.2, R6.2, R9.2, R12.2, R15.2, R16.2
unnamed: Q1.2 (B), R1.1
unnamed: C2.1, Q1.1 (E), R2.1
unnamed: C2.2, Q2.2 (B), R3.1, R4.1, R5.1
unnamed: Q2.1 (E), R6.1, R18.1
unnamed: Q3.2 (B), R7.1
unnamed: Q3.3 (C), R18.2
unnamed: Q3.1 (E), Q4.2 (B)
unnamed: Q4.3 (C), Q5.2 (B), R8.2
unnamed: Q6.2 (B), R10.1
unnamed: Q6.3 (C), Q7.2 (B), R11.2
unnamed: Q8.2 (B), R13.1
unnamed: Q8.3 (C), Q9.2 (B), R14.2
unnamed: Q10.2 (B), R17.1
VCC: C1.2, J6.1, J7.1, J8.1, Q1.3 (C), Q2.3 (C), Q5.3 (C), Q7.3 (C), Q9.3 (C), Q10.3 (C), R8.1, R11.1, R14.1

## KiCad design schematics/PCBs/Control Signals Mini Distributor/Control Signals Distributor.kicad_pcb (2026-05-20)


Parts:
C1, C2: 0.1uF; C_Disc_D4.3mm_W1.9mm_P5.00mm
J1: IN; PinHeader_1x08_P2.54mm_Vertical
J2, J3, J4: POWER; PinHeader_1x02_P2.54mm_Vertical
J5: OUT; PinHeader_1x08_P2.54mm_Vertical
R1, R2, R3, R4, R5, R6, R7, R8: 1K; R_Axial_DIN0309_L9.0mm_D3.2mm_P12.70mm_Horizontal
TP1, TP2: TestPoint; TestPoint_THTPad_D2.0mm_Drill1.0mm

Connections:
/Bit Inverter 0/IN: J1.1, R1.2; also elsewhere on the board
/Bit Inverter 0/OUT: J5.1; also elsewhere on the board
/Bit Inverter 1/IN: J1.2, R2.2; also elsewhere on the board
/Bit Inverter 1/OUT: J5.2; also elsewhere on the board
/Bit Inverter 2/IN: J1.3, R3.2; also elsewhere on the board
/Bit Inverter 2/OUT: J5.3; also elsewhere on the board
/Bit Inverter 3/IN: J1.4, R4.2; also elsewhere on the board
/Bit Inverter 3/OUT: J5.4; also elsewhere on the board
/Bit Inverter 4/IN: J1.5, R5.2; also elsewhere on the board
/Bit Inverter 4/OUT: J5.5; also elsewhere on the board
/Bit Inverter 5/IN: J1.6, R6.2; also elsewhere on the board
/Bit Inverter 5/OUT: J5.6; also elsewhere on the board
/Bit Inverter 6/IN: J1.7, R7.2; also elsewhere on the board
/Bit Inverter 6/OUT: J5.7; also elsewhere on the board
/Bit Inverter 7/IN: J1.8, R8.2; also elsewhere on the board
/Bit Inverter 7/OUT: J5.8; also elsewhere on the board
GND: C1.2, C2.2, J2.2, J3.2, J4.2; also elsewhere on the board
VCC: C1.1, C2.1, J2.1, J3.1, J4.1, R1.1, R2.1, R3.1, R4.1, R5.1, R6.1, R7.1, R8.1, TP1.1, TP2.1; also elsewhere on the board

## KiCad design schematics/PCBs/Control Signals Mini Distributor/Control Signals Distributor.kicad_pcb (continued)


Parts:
D1: LED; LED_D5.0mm
Q1, Q2: 2N2222; TO-92_Inline
R17, R18: 1K; R_Axial_DIN0309_L9.0mm_D3.2mm_P12.70mm_Horizontal
R19: 10K; R_Axial_DIN0309_L9.0mm_D3.2mm_P12.70mm_Horizontal

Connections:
/Bit Inverter 0/IN: Q1.2 (B); also elsewhere on the board
/Bit Inverter 0/OUT: D1.2 (A), Q2.1 (E), R19.1; also elsewhere on the board
GND: Q1.1 (E), R18.2, R19.2; also elsewhere on the board
unnamed: D1.1 (K), R18.1
unnamed: Q1.3 (C), Q2.2 (B), R17.2
VCC: Q2.3 (C), R17.1; also elsewhere on the board

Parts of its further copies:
D2, D3, D4, D5, D6, D7, D8: LED; LED_D5.0mm
Q3, Q4, Q5, Q6, Q7, Q8, Q9, Q10, Q11, Q12, Q13, Q14, Q15, Q16: 2N2222; TO-92_Inline
R20, R21, R23, R24, R26, R27, R29, R30, R32, R33, R35, R36, R38, R39: 1K; R_Axial_DIN0309_L9.0mm_D3.2mm_P12.70mm_Horizontal
R22, R25, R28, R31, R34, R37, R40: 10K; R_Axial_DIN0309_L9.0mm_D3.2mm_P12.70mm_Horizontal

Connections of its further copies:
/Bit Inverter 1/IN: Q3.2 (B); also elsewhere on the board
/Bit Inverter 1/OUT: D2.2 (A), Q4.1 (E), R22.1; also elsewhere on the board
/Bit Inverter 2/IN: Q5.2 (B); also elsewhere on the board
/Bit Inverter 2/OUT: D3.2 (A), Q6.1 (E), R25.1; also elsewhere on the board
/Bit Inverter 3/IN: Q7.2 (B); also elsewhere on the board
/Bit Inverter 3/OUT: D4.2 (A), Q8.1 (E), R28.1; also elsewhere on the board
/Bit Inverter 4/IN: Q9.2 (B); also elsewhere on the board
/Bit Inverter 4/OUT: D5.2 (A), Q10.1 (E), R31.1; also elsewhere on the board
/Bit Inverter 5/IN: Q11.2 (B); also elsewhere on the board
/Bit Inverter 5/OUT: D6.2 (A), Q12.1 (E), R34.1; also elsewhere on the board
/Bit Inverter 6/IN: Q13.2 (B); also elsewhere on the board
/Bit Inverter 6/OUT: D7.2 (A), Q14.1 (E), R37.1; also elsewhere on the board
/Bit Inverter 7/IN: Q15.2 (B); also elsewhere on the board
/Bit Inverter 7/OUT: D8.2 (A), Q16.1 (E), R40.1; also elsewhere on the board
GND: Q3.1 (E), Q5.1 (E), Q7.1 (E), Q9.1 (E), Q11.1 (E), Q13.1 (E), Q15.1 (E), R21.2, R22.2, R24.2, R25.2, R27.2, R28.2, R30.2, R31.2, R33.2, R34.2, R36.2, R37.2, R39.2, R40.2; also elsewhere on the board
unnamed: D2.1 (K), R21.1
unnamed: D3.1 (K), R24.1
unnamed: D4.1 (K), R27.1
unnamed: D5.1 (K), R30.1
unnamed: D6.1 (K), R33.1
unnamed: D7.1 (K), R36.1
unnamed: D8.1 (K), R39.1
unnamed: Q3.3 (C), Q4.2 (B), R20.2
unnamed: Q5.3 (C), Q6.2 (B), R23.2
unnamed: Q7.3 (C), Q8.2 (B), R26.2
unnamed: Q9.3 (C), Q10.2 (B), R29.2
unnamed: Q11.3 (C), Q12.2 (B), R32.2
unnamed: Q13.3 (C), Q14.2 (B), R35.2
unnamed: Q15.3 (C), Q16.2 (B), R38.2
VCC: Q4.3 (C), Q6.3 (C), Q8.3 (C), Q10.3 (C), Q12.3 (C), Q14.3 (C), Q16.3 (C), R20.1, R23.1, R26.1, R29.1, R32.1, R35.1, R38.1; also elsewhere on the board


Board: 2 copper layers, 33.0 x 115.6 mm, 65 parts (0 on the bottom side), 34 nets.

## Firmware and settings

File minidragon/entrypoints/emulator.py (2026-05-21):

import argparse
import os
import serial  # type: ignore
import sys
import termios
import time
import tty
from io import FileIO
from typing import Any, Final, List, Optional

from ..core import CPUCore, MemoryFilter


ROM_LOCATION: Final[int] = 0x0000
ROM_SIZE: Final[int] = 0x7800
PERIPHERALS_LOCATION: Final[int] = 0x7800
PERIPHERALS_SIZE: Final[int] = 0x800
CART_LOCATION: Final[int] = 0x8000
CART_SIZE: Final[int] = 0x4000
RAM_LOCATION: Final[int] = 0xC000
RAM_SIZE: Final[int] = 0x4000


class ExpansionBus:
    def __init__(self) -> None:
        self.value = 0


class Cartridge:
    def __init__(self, expansion: ExpansionBus, data: bytes, banks: int = 1) -> None:
        self.expansion = expansion
        self.data = data

        # Cartridge bank control.
        self.cb = 0

        # Cartridge input, always 0 for now.
        self.ci = 0

        # Cartridge bank configuration, always 1 executable page for now.
        self.cbc = banks

    def read(self, address: int) -> int:
        if address < 0:
            address = 0
        address = address & 0x3FFF
        address |= (self.cb << 15)

        if address >= len(self.data):
            return 0
        return self.data[address]

    def write(self, address: int, data: int) -> Optional[int]:
        # Right now, cartridges are emulated as read-only.
        return None

    def tick(self, cycles: int, instructions: int) -> None:
        # Nothing happens for carts right now, they're essentially ROM boards.
        pass


class EmptyCartridge(Cartridge):
    def __init__(self, expansion: ExpansionBus) -> None:
        super().__init__(expansion, b"", banks=0)


class Peripheral:
    def __init__(self, slot: int, expansion: ExpansionBus, verbose: bool) -> None:
        # What peripheral slot this is addressed under.
        self.slot = slot
        self.expansion = expansion
        self.verbose = verbose

    def log(self, data: str) -> None:
        if self.verbose:
            print(data, file=sys.stderr)

    def read(self, address: int) -> int:
        return 0

    def write(self, address: int, value: int) -> None:
        pass

    def tick(self, cycles: int, instructions: int) -> None:
        pass


class R6551AP(Peripheral):
    def __init__(self, expansion: ExpansionBus, port: Optional[str], verbose: bool) -> None:
        super().__init__(0, expansion, verbose)

        # Status register bits.
        self.irq = False
        self.dsr = False
        self.dcd = False
        self.tdre = True
        self.rdrf = False
        self.ovrn = False
        self.fe = False
        self.pe = False

        # Control register.
        self.sbn = 1
        self.wl = 8
        self.rcs = 0
        self.sbr = 0

        # Command register.
        self.pmc = 0
        self.pme = 0
        self.rem = 0
        self.tic = 0
        self.ird = 0
        self.dtr = 0

        self.__port = port
        self.__conn: Optional[serial.Serial] = None
        self.__recvd: Optional[int] = None
        self.__txw: Optional[float] = None
        self.__rxw: Optional[float] = None

        self.__stdin: Optional[FileIO] = None
        self.__stdout: Optional[FileIO] = None
        self.__old: Optional[Any] = None
        if self.__port is None:
            os.set_blocking(0, False)
            self.__stdin = os.fdopen(0, 'rb', buffering=0)
            self.__stdout = os.fdopen(1, 'wb', buffering=0)

            # Ensure that the terminal emulator we're under doesn't buffer input before sending to us.
            self.__old = termios.tcgetattr(self.__stdin.fileno())
            tty.setcbreak(self.__stdin.fileno(), termios.TCSANOW)

    def __del__(self) -> None:
        if self.__old and self.__stdin:
            termios.tcsetattr(self.__stdin.fileno(), termios.TCSADRAIN, self.__old)
            os.set_blocking(0, True)

    def _baud(self) -> Optional[int]:
        if self.sbr == 1:
            return 50
        elif self.sbr == 2:
            return 75
        elif self.sbr == 3 or self.sbr == 4:
            # Fractional baud rates, unsupported.
            return None
        elif self.sbr == 5:
            return 150
        elif self.sbr == 6:
            return 300
        elif self.sbr == 7:
            return 600
        elif self.sbr == 8:
            return 1200
        elif self.sbr == 9:
            return 1800
        elif self.sbr == 10:
            return 2400
        elif self.sbr == 11:
            return 3600
        elif self.sbr == 12:
            return 4800
        elif self.sbr == 13:
            return 7200
        elif self.sbr == 14:
            return 9600
        elif self.sbr == 15:
            return 19200
        else:
            raise Exception("Logic error, invalid SBR value!")

    def _time(self) -> float:
        baud = self._baud()
        if baud is None:
            raise Exception("No valid baud rate, can't calculate wait!")

        bitwidth = 1.0 / baud

        if self.pme:
            if self.pmc == 0:
                parity = 1
            elif self.pmc == 1:
                parity = 1
            else:
                # Invalid, but calculate anyway.
                parity = 0
        else:
            parity = 0

        bits = self.wl + self.sbn + parity
        return float(bits) * bitwidth

    def _conn(self) -> Optional[serial.Serial]:
        if self.__conn is not None:
            return self.__conn

        # Figure out parameters for serial.
        if self.sbr == 0 or self.rcs == 0:
            # Invalid configuration, we don't support external clock.
            self.log("R6551AP configured for external clock, ignoring Rx/Tx.")
            return None

        baud = self._baud()
        if baud is None:
            # Invalid fractional baud rate, don't support it.
            self.log("R6551AP configured for unsupported baud rate, ignoring Rx/Tx.")
            return None

        if self.wl == 5:
            bytesize = serial.FIVEBITS
        elif self.wl == 6:
            bytesize = serial.SIXBITS
        elif self.wl == 7:
            bytesize = serial.SEVENBITS
        elif self.wl == 8:
            bytesize = serial.EIGHTBITS

        if self.pme:
            if self.pmc == 0:
                parity = serial.PARITY_ODD
            elif self.pmc == 1:
                parity = serial.PARITY_EVEN
            else:
                # Invalid configuration, don't support parity mark/space.
                self.log("R6551AP configured for unsupported mark/space parity, ignoring Rx/Tx.")
                return None
        else:
            parity = serial.PARITY_NONE

        if self.sbn == 0:
            stopbits = serial.STOPBITS_ONE
        else:
            if bytesize == serial.EIGHTBITS and parity != serial.PARITY_NONE:
                stopbits = serial.STOPBITS_ONE
            elif bytesize == serial.FIVEBITS and parity == serial.PARITY_NONE:
                stopbits = serial.STOPBITS_ONE_POINT_FIVE
            else:
                stopbits = serial.STOPBITS_TWO

        self.__conn = serial.Serial(
            port=self.__port,
            baudrate=baud,
            bytesize=bytesize,
            parity=parity,
            stopbits=stopbits,
            timeout=0,
        )
        return self.__conn

    def _txb(self, byte: int) -> None:
        if self.tic == 0:
            # Transmitter disabled.
            self.log("R6551AP transmitter disabled, ignoring Tx.")
            return

        if self.__txw is not None:
            if self.__txw > time.time():
                # Sent another byte when the previous was sending. Drop it.
                self.log("R6551AP dropping Tx byte requested before Tx ready.")
                return

        if self.__port is None:
            # Just output on stdout.
            self.tdre = False
            if self.irq:
                self.irq = self.dsr or self.dcd or self.rdrf or self.tdre
            self.__txw = time.time() + self._time()

            if self.__stdout is None:
                raise Exception("Logic error, shouldn't have null stdout in non-serial port mode!")
            self.__stdout.write(bytes([byte]))
            self.__stdout.flush()
        else:
            # Might need to open serial port, might be able to use existing.
            conn = self._conn()
            if conn:
                self.tdre = False
                if self.irq:
                    self.irq = self.dsr or self.dcd or self.rdrf or self.tdre
                self.__txw = time.time() + self._time()
                conn.write(bytes([byte]))
            else:
                self.log("Impossible condition, ignoring Tx.")

    def _rxb(self) -> Optional[int]:
        if self.rcs == 0:
            # Misconfigured to read with external receiver clock, which we aren't
            # going to use in hardware. So, refuse to ever read to emulate being
            # configured wrong.
            return None

        if self.__port is None:
            if self.__stdin is None:
                raise Exception("Logic error, shouldn't have null stdin in non-serial port mode!")

            byte = self.__stdin.read(1)
            if byte is None:
                return None

            # Experimentally, an actual VT-102 tends to send characters at about 625
            # bits per second, not the full 9600 bits per second. So, hardcode that
            # here.
            waittime = self._time()
            if waittime < 0.016:
                waittime = 0.016

            self.__rxw = time.time() + waittime
            data = byte[0]

            # Convert delete to backspace (^H) since this is what a VT-100 would send.
            if data == 127:
                data = 8

            return data
        else:
            # Might need to open serial port, might be able to use existing.
            conn = self._conn()
            if conn:
                data = conn.read(1)
                if data:
                    if len(data) > 1:
                        raise Exception("Logic error, got too many bytes back from serial!")

                    # No need to simulate Rx delays with real hardware, so not
                    # setting the Rx wait flag.
                    return int(data[0])
            else:
                self.log("Impossible condition, ignoring Rx.")

            return None

    def tick(self, cycles: int, instructions: int) -> None:
        # Attempt to read a byte from our interface.
        if self.__rxw is not None:
            if self.__rxw <= time.time():
                # Time elapsed for receive.
                self.__rxw = None

        if self.__rxw is None:
            read = self._rxb()
            if read:
                # See if we overran the buffer or not.
                if self.__recvd is not None:
                    self.log("R6551AP overran Rx buffer, dropping incoming byte.")
                    self.ovrn = True
                else:
                    self.__recvd = read
                    self.rdrf = True
                    self.irq = True

        # Attempt to clear the transmit blocked status.
        if self.__txw is not None:
            if self.__txw <= time.time():
                # Time elapsed for transmit.
                self.tdre = True
                self.irq = True
                self.__txw = None

    def read(self, address: int) -> int:
        register = address & 0x3

        if register == 0:
            # Read receiver data register.
            if self.__recvd is not None:
                val = self.__recvd
                self.__recvd = None
                self.rdrf = False
            else:
                self.log("R6551AP read empty Rx buffer, returning zero.")
                val = 0

            # Ensure that we set/clear the IRQ bit based on if there's
            # another interrupt available.
            if self.irq:
                self.irq = self.dsr or self.dcd or self.rdrf or self.tdre

            return val

        elif register == 1:
            # Read status register.
            val = (
                (0x80 if self.irq else 0x00) +
                (0x40 if self.dsr else 0x00) +
                (0x20 if self.dcd else 0x00) +
                (0x10 if self.tdre else 0x00) +
                (0x08 if self.rdrf else 0x00) +
                (0x04 if self.ovrn else 0x00) +
                (0x02 if self.fe else 0x00) +
                (0x01 if self.pe else 0x00)
            )

            # Clear interrupt bit.
            self.irq = False

            return val

        elif register == 2:
            # Read command register.
            val = (
                ((self.pmc & 0x3) << 6) +
                (0x20 if self.pme else 0x00) +
                (0x10 if self.rem else 0x00) +
                ((self.tic & 0x3) << 2) +
                (0x02 if self.ird else 0x00) +
                (0x01 if self.dtr else 0x00)
            )

            return 0

        elif register == 3:
            # Read control register.
            if self.wl == 8:
                wlv = 0
            elif self.wl == 7:
                wlv = 1
            elif self.wl == 6:
                wlv = 2
            elif self.wl == 5:
                wlv = 3
            else:
                raise Exception("Logic error, invalid WL value!")

            val = (
                (0x80 if self.sbn == 2 else 0x00) +
                (wlv << 5) +
                (0x10 if self.rcs else 0x00) +
                (self.sbr & 0x0F)
            )

            return val

        else:
            raise Exception("Logic error, invalid register!")

    def write(self, address: int, value: int) -> None:
        register = address & 0x3

        if register == 0:
            # Write transmit data register.
            self._txb(value)

        elif register == 1:
            # Programmed reset.
            self.ovrn = False

            self.rem = 0
            self.tic = 0
            self.ird = 0
            self.dtr = 0

            self.log("R6551AP software reset, clearing overrun flag.")

        elif register == 2:
            # Write command register.
            old_pmc = self.pmc
            old_pme = self.pme

            self.pmc = (value >> 6) & 0x3
            self.pme = (value >> 5) & 0x1
            self.rem = (value >> 4) & 0x1
            self.tic = (value >> 2) & 0x3
            self.ird = (value >> 1) & 0x1
            self.dtr = (value >> 1) & 0x1

            if self.pmc != old_pmc or self.pme != old_pme:
                # Changed parity settings, might need to refresh serial connection.
                self.__conn = None

        elif register == 3:
            # Write control register.
            old_sbn = self.sbn
            old_wl = self.wl
            old_sbr = self.sbr

            # Stop bit number.
            self.sbn = 2 if bool((value >> 7) & 0x1) else 1

            # Word length.
            wl = (value >> 5) & 0x3
            if wl == 0:
                self.wl = 8
            elif wl == 1:
                self.wl = 7
            elif wl == 2:
                self.wl = 6
            elif wl == 3:
                self.wl = 5

            # Receiver clock source.
            self.rcs = (value >> 4) & 0x1

            # Selected Baud Rate.
            self.sbr = value & 0xF

            if self.sbn != old_sbn or self.wl != old_wl or self.sbr != old_sbr:
                # Changed baud, stop or bits settings, might need to refresh serial connection.
                self.__conn = None

        else:
            raise Exception("Logic error, invalid register!")


class CCR(Peripheral):
    def __init__(self, expansion: ExpansionBus, cartridge: Cartridge, verbose: bool) -> None:
        # What peripheral slot this is addressed under.
        super().__init__(7, expansion, verbose)

        self.cartridge = cartridge
        self.cycles = 0
        self.instructions = 0

    def read(self, address: int) -> int:
        if address == 0:
            # Bottom 4 bits are the cartridge bank control, upper 4 are always zeros.
            return self.cartridge.cb & 0xF
        if address == 1:
            # Bottom 4 bits are the cartridge bank configuration, upper 4 are cartridge input.
            return (self.cartridge.cbc & 0xF) | ((self.cartridge.ci & 0xF) << 4)
        if address == 2:
            # 8 expansion bits readable as a register.
            return self.expansion.value & 0xFF

        # No other registers.
        return 0

    def write(self, address: int, value: int) -> None:
        if address == 0:
            # Bottom 4 bits are the cartridge bank control, writing changes the bank.
            self.cartridge.cb = value & 0xF

        if address == 255:
            # Special debug trigger instruction, output CPU cycles and instructions.
            print(f"Current cycles: {self.cycles}, current instructions: {self.instructions}", file=sys.stderr)

    def tick(self, cycles: int, instructions: int) -> None:
        self.cycles = cycles
        self.instructions = instructions


class MiniDragonMemoryFilter(MemoryFilter):
    def __init__(self, peripherals: List[Peripheral], cartridge: Cartridge, verbose: bool) -> None:
        self.peripherals = {p.slot: p for p in peripherals}
        self.cartridge = cartridge
        self.verbose = verbose

    def log(self, data: str) -> None:
        if self.verbose:
            print(data, file=sys.stderr)

    def tick(self, cycles: int, instructions: int) -> None:
        for peripheral in self.peripherals.values():
            peripheral.tick(cycles, instructions)
        self.cartridge.tick(cycles, instructions)

    def read(self, address: int) -> Optional[int]:
        # Bottom part of memory is the ROM file. top 2KB of ROM space is
        # where the peripherals are mapped.
        if address < PERIPHERALS_LOCATION or address >= RAM_LOCATION:
            return None

        if address >= CART_LOCATION:
            return self.cartridge.read(address - CART_LOCATION)

        # Calculate peripheral offset, pass off to the peripheral's impl.
        slot = (address - PERIPHERALS_LOCATION) // 0x100
        offset = (address - PERIPHERALS_LOCATION) % 0x100

        if slot in self.peripherals:
            return self.peripherals[slot].read(offset)
        else:
            return 0

    def write(self, address: int, data: int) -> Optional[int]:
        if address < PERIPHERALS_LOCATION:
            # ROM is not writeable, refuse to update the contents.
            self.log(f"Ignoring write of {hex(data)} to ROM address {address}!")
            return None
        if address >= RAM_LOCATION:
            # RAM is directly writeable, pass the data value on.
            return data
        if address >= CART_LOCATION:
            # Cart space is writeable, pass the data value on.
            return self.cartridge.write(address - CART_LOCATION, data)

        # Calculate peripheral offset, pass off to the peripheral's impl.
        slot = (address - PERIPHERALS_LOCATION) // 0x100
        offset = (address - PERIPHERALS_LOCATION) % 0x100

        if slot in self.peripherals:
            self.peripherals[slot].write(offset, data)

        # System memory is "read only" in this location, nothing gets updated
        # outside of the peripherals themselves.
        return None


def main(boot_rom: str, cartridge: Optional[str], serial_port: Optional[str], verbose: bool) -> int:
    # First, fill the ROM portion with the bootROM file itself.
    with open(boot_rom, "rb") as bfp:
        data = bfp.read()
    if len(data) > ROM_SIZE:
        data = data[:ROM_SIZE]
    if len(data) < ROM_SIZE:
        data = data + b"\x00" * (ROM_SIZE - len(data))

    memory = [0] * 0x10000
    for i, byte in enumerate(data):
        memory[i] = byte

    # Expansion bus is emulated but currently unused. It's only available on the
    # peripheral board but it's wired to all peripherals an the cart slot.
    expansion = ExpansionBus()

    # Load any cartridge presented.
    if cartridge:
        with open(cartridge, "rb") as bfp:
            cdata = bfp.read()
            chw = Cartridge(expansion, cdata)
    else:
        chw = EmptyCartridge(expansion)

    # Hook up peripherals to the system.
    ram_filter = MiniDragonMemoryFilter(
        [
            R6551AP(expansion, serial_port, verbose),
            CCR(expansion, chw, verbose),
        ],
        chw,
        verbose,
    )

    # Calculate how much time a single tick should take as a fraction of a second.
    ticktime = 1.0 / 18000.0

    # Now, instantiate the CPU core and run until a halt instruction is encountered.
    cpu = CPUCore(memory, ram_filter)
    after = time.time()
    try:
        while True:
            if cpu.mnemonic == "HALT":
                print("\nCPU halted.", file=sys.stderr)
                break

            # Get the timing from the last instruction so we can be accurate about speed.
            cycles = cpu.cycles
            before = after

            cpu.tick()
            ram_filter.tick(cpu.cycles, cpu.ticks)

            # The real CPU runs at ~18.0KHz, simulate that here.
            cycles = cpu.cycles - cycles
            expected = float(cycles) * ticktime
            after = time.time()
            catchup = expected - (after - before)

            if catchup > 0.0:
                waittime = after + catchup
                while (actual := time.time()) < waittime:
                    pass

                # Compensate for overrun by rewinding time.
                after = waittime - (actual - waittime)
    except KeyboardInterrupt:
        print("\nExecution interrupted by user.", file=sys.stderr)

    return 0
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

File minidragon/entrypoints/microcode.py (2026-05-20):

import argparse
import os
from typing import List
from ..core import InstructionLoadControlSignals, ControlSignals, instructions


def count_jumpers(line: str) -> int:
    count: int = 0
    for char in line:
        if char == "X":
            count += 1
    return count


def format_line(microcode: str) -> str:
    if len(microcode) != 32:
        raise Exception("Logic error, unexpected number of microcodes!")

    return f"{microcode[0:8]} {microcode[8:16]} {microcode[16:24]} {microcode[24:32]}"


if __name__ == "__main__":
    parser = argparse.ArgumentParser(
        description="Generates microcode programming lines."
    )
    parser.add_argument(
        "-f",
        "--file",
        type=str,
        help="Output to a file instead of stdout.",
    )
    args = parser.parse_args()
    microcodes: List[str] = []
    jumpers: int = 0
    holes: int = 0
    boards: int = 0
    miniboards: int = 0

    def append_microcode(step: ControlSignals) -> None:
        global jumpers
        global holes

        # The hard part is mapping the individual control lines to the
        # microcode boards. We do this based on the instruction decoder
        # schematic. The instruction decoder logic works as an
        # open-collector memory system, but the bus termination circuit
        # does an invert for us, so we represent a "0" with a ".",
        # or lack of jumper, and a "1" with a "X", or request for a
        # jumper in that spot.
        microcode: str = ""

        # Calculate immediate register control signals.
        immsrc: int = 0
        if step.z_output:
            immsrc = 1
        elif step.imm_6_output:
            immsrc = 2
        elif step.imm_4_output:
            immsrc = 3

        # Calculate the data bus high control signals.
        dbus: int = 0
        if step.alu_output:
            dbus = 1
        elif step.d_high_output:
            dbus = 2
        elif step.a_high_output:
            dbus = 3

        # Bit 0
        microcode += "X" if step.ip_input else "."
        microcode += "X" if step.ir_input else "."
        microcode += "X" if step.a_input else "."
        microcode += "X" if step.b_input else "."

        # Bit 4
        microcode += "X" if step.c_input else "."
        microcode += "X" if step.d_input else "."
        microcode += "X" if step.p_input else "."
        microcode += "X" if step.sram_input else "."

        # Bit 8
        microcode += "X" if step.flags_input else "."
        microcode += "X" if (dbus & 0x2) != 0 else "."
        microcode += "X" if (dbus & 0x1) != 0 else "."
        microcode += "X" if step.alu_low_output else "."

        # Bit 12
        microcode += "X" if step.a_output else "."
        microcode += "X" if step.d_output else "."
        microcode += "X" if step.u_output else "."
        microcode += "X" if step.sram_output else "."

        # Bit 16
        microcode += "X" if step.flags_output else "."
        microcode += "X" if step.pc_swap else "."
        microcode += "X" if (step.alu_src & 0x2) != 0 else "."
        microcode += "X" if (step.alu_src & 0x1) != 0 else "."

        # Bit 20
        microcode += "X" if (step.carry & 0x2) != 0 else "."
        microcode += "X" if (step.carry & 0x1) != 0 else "."
        microcode += "X" if (step.alu_op & 0x4) != 0 else "."
        microcode += "X" if (step.alu_op & 0x2) != 0 else "."

        # Bit 24
        microcode += "X" if (step.alu_op & 0x1) != 0 else "."
        microcode += "X" if (immsrc & 0x2) != 0 else "."
        microcode += "X" if (immsrc & 0x1) != 0 else "."
        microcode += "X" if (step.address_src & 0x1) != 0 else "."

        # Bit 28
        microcode += "X" if step.v_output else "."
        microcode += "X" if step.u_input else "."
        microcode += "X" if step.v_input else "."
        # This isn't the last instruction, so don't reset the
        # microcode counter.
        microcode += "."

        # Keep track of how many jumpers we will need
        jumpers += count_jumpers(microcode)
        holes += (32 - count_jumpers(microcode))
        microcodes.append(format_line(microcode))

    microcodes.append("Instruction Load")
    append_microcode(InstructionLoadControlSignals())
    microcodes.append("ROM boards: 0")
    microcodes.append("MiniROM boards: 1")
    miniboards += 1
    microcodes.append("")

    for instruction in instructions:
        try:
            signals = instruction.signals()
        except Exception:
            # Skip over macro instructions, we don't need to opcode those.
            continue

        microcodes.append(instruction.__class__.__name__)
        for num, step in enumerate(signals):
            append_microcode(step)
            if num % 4 == 3:
                microcodes.append("")

        # One-indexed instead of zero-indexed, and add one for the early
        # terminate. One-indexed because the first ROM board for every
        # instruction is the instruction load control signals which is
        # handled using special hardware when detecting the 0'th position
        # in the microcode counter circuit.
        actual = num + 2
        if (actual % 4) == 1:
            # We can do a regular board followed by a mini-board.
            addboards = actual // 4
            addminiboards = 1
        else:
            # Round up, so two or more of the microcodes go onto the
            # last board.
            addboards = (actual + 3) // 4
            addminiboards = 0

        boards += addboards
        miniboards += addminiboards

        # Append an "early terminate" signal to the microcode counter if we
        # haven't run out of room.
        if num < 15:
            # We can cheat, we don't care about the rest of the signals since
            # we're going to reset the microcode counter asynchronously,
            # looking up the next instruction in the process.
            microcodes.append(format_line("...............................X"))
            jumpers += 1
            holes += 31
        else:
            raise Exception(
                "Cannot generate microcode reset signal, this instruction "
                "will infinite loop!"
            )

        while actual % 4 in {2, 3}:
            microcodes.append(format_line("................................"))
            actual += 1

        microcodes.append(f"ROM boards: {addboards}")
        microcodes.append(f"MiniROM boards: {addminiboards}")
        microcodes.append("")

    microcodes.append(f"Total jumpers: {jumpers}")
    microcodes.append(f"Total holes: {holes}")
    microcodes.append(f"Total ROM boards: {boards}")
    microcodes.append(f"Total MiniROM boards: {miniboards}")

    if args.file:
        with open(args.file, "w") as fp:
            fp.write(os.linesep.join(microcodes))
    else:
        print(os.linesep.join(microcodes))

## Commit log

2026-05-20 Add support for macros and constants in assembler; make compiler module optional
2026-05-21 Add unit tests for assembler macros and constants, including edge cases and recursion limits Move tests to own sub package, there will probably be more accumulating over time
2026-05-21 Handle user interruption gracefully in emulator loop and fix non-blocking stdin teardown logic
    [emulator.py]
2026-05-21 Add tests for HALT detection and memory filter edge cases
